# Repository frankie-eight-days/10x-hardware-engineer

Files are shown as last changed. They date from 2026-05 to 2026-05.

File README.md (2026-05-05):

# 10x Hardware Engineer

An experiment in agent-driven, full-stack open-source hardware: design a Linux-class dev board from datasheet to shell prompt with as much LLM automation as physically possible, then write up what worked and what didn't.

## The board

**Target MPU:** NXP i.MX 6ULL (MCIMX6Y2CVM08AB, ~$5–6 @ qty 10)
- Cortex-A7 @ 800 MHz, MAPBGA-289, 0.8 mm pitch (forgiving for an open-stack BGA fanout)
- External DDR3, 2× 10/100 Ethernet MAC, USB 2.0 OTG, I²S, UART, SPI, USDHC
- Mainline Linux + U-Boot, NXP Yocto BSP, Olimex OLinuXino open KiCad reference

**Peripherals (v1 spec):**
- 256–512 MB DDR3L (Micron / Nanya, 16-bit, JLC stock permitting)
- 1× RJ45 Ethernet (LAN8720A or KSZ8081 PHY) — talk to it over the home LAN
- USB 2.0 host/OTG (also doubles as i.MX serial-download recovery — unbrick without JTAG)
- microSD slot (primary boot)
- Optional QSPI / eMMC footprint (stretch)
- I²S Class-D audio amp (MAX98357A) + speaker pads — fun ngspice subject
- USB-UART bridge (CH340N, JLC Basic) for the shell, plus 4-pin TTL UART header
- 10-pin Cortex JTAG/SWD header (don't ship without it)
- PMIC: PCA9450 or PF3000 (TBD — pick what JLC has stocked)

## The stack

| Layer | Tool | Notes |
|---|---|---|
| Datasheet RAG | Docling → LanceDB hybrid → custom FastMCP | Required citations on every answer |
| Block diagrams | Mermaid (source-of-truth) + drawio MCP | mermaid diffs in git, drawio for blog |
| Schematic | atopile (`.ato`) | parametric `pick_part`, JLC-aware |
| Parts | jlcparts SQLite + easyeda2kicad | offline part DB + symbol/footprint pulls |
| Layout | KiCad 9 + Seeed kicad-mcp-server | 39-tool MCP |
| Routing | KiCad PNS (DDR3, USB, ENET) + Freerouting CLI (boring nets) | hybrid; agent does length-tune constraints |
| Sim | ngspice + InSpice | power rails, PMIC loop, Class-D filter |
| Fab/PCBA | JLCPCB API | basic/preferred parts where possible |
| Firmware build | Buildroot + mainline U-Boot + mainline Linux | Yocto is overkill |
| Firmware debug | OpenOCD + JTAG + serial-download recovery | |
| LLM | Opus 4.7 (1M) for layout/DDR; Sonnet 4.6 for cheap Q&A | prompt-cache datasheet + HDG |

## Phases

1. **Hardware capture** — block diagram → atopile modules → KiCad netlist → BOM
2. **Layout** — placement, BGA escape, DDR3 length-matching, Ethernet diff pairs, fab files
3. **Bring-up** — power-on, UART, U-Boot from SD
4. **Linux** — kernel + Buildroot rootfs, shell over UART
5. **Network** — DHCP, SSH from laptop
6. **Audio demo** — I²S out to the Class-D amp, play a sine wave from userland
7. **Blog** — honest write-up: what the agents did, what they got wrong, where humans had to step in

## Why this is supposed to be novel

Quilter shipped an i.MX 8M Mini DDR4 board with an autonomous physics engine in 40 hours — closed-source. atopile / tscircuit / Diode have shipped public LLM-driven schematics but only on 2-layer ESP32-class boards. **Nobody has publicly crossed the DDR Rubicon on a fully open agent stack.** That's the gap.

## Status

Scaffolding. See [PLAN.md](PLAN.md) for the decision log and open questions.

## License

MIT.

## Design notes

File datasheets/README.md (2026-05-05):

# Datasheets

PDFs are git-ignored (too big). Fetch with `scripts/fetch_datasheets.sh` (TODO) or by hand.

## Acquired

| File | Pages | Source | Notes |
|---|---|---|---|
| `raw/imx6ull-MCIMX6Y2CVM08AB-datasheet.pdf` | 138 | bundled with reference design | NXP i.MX 6ULLIEC rev 1.2 (2017). Full electricals + ordering + DDR/MMDC + boot config. Authoritative. |
| `raw/imx6ull-hardware-guide.pdf` | 12 | nxp.com (AN5121) | i.MX 6ULL Hardware Design Checklist — short. |
| `raw/ddr3-nanya-NT5CC128M16JR.pdf` | — | bundled | Nanya 2 Gb DDR3-1600 ×16. **Probable DDR3 choice.** |
| `raw/ref-bundle/NT5CC256M16{DP,EP}.pdf` | — | bundled | Nanya 4 Gb DDR3 alternates. |
| `raw/emmc-MKEMB008GT1E.pdf` | — | bundled | 8 GB eMMC (stretch goal). |
| `raw/imx6ull-core-board-reference-schematic.pdf` | — | bundled | Full schematic of `yu-mingfu/IMX6ULL_Core_Board` — DDR3 byte-lane wiring, power tree, eMMC, connector. **Crib heavily.** |
| `raw/imx6ull-reference-manual.pdf` | **3899** | whqee.cn mirror | NXP **IMX6ULLRM Rev 0** (Sep 2016). Full register-level manual. Authoritative. |
| `raw/imx6ull-hardware-developer-guide.pdf` | 53 | zlgmcu.com mirror | NXP **IMX6ULLHDG Rev 0** (Aug 2016). DDR3 + USB + Ethernet routing rules. |

## Still pending

- **AN5198** — i.MX 6UL/6ULL DDR Calibration.
- **AN12042** — i.MX 6UL/6ULL DDR3L Layout Guidelines.
- **AN5187** — Power Consumption.

## Pending fetch (public)

- Datasheets for our peripheral choices once finalized:
  - PMIC: PCA9450 / PF3000 / PF1550
  - Ethernet PHY: LAN8720A or LAN8742A
  - I²S amp: MAX98357A
  - USB-UART: CH340N
  - microSD socket: Hirose DM3 / Molex 502774

## Next step (RAG ingest)

Run **Docling** on every PDF in `raw/` → `parsed/` markdown + figure PNGs + per-page citations. Index with LanceDB hybrid (BM25 + dense embeddings). Serve via custom FastMCP at `mcp/datasheet-server/` exposing `lookup_register`, `lookup_pin`, `get_electrical_limit`, `get_routing_rule`. See repo `PLAN.md` for the full RAG strategy.

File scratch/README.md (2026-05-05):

# scratch

Throwaway atopile experiments — not the real board. Used to validate the toolchain and try syntax.

## hello_resistor

Single 10 kΩ pull-down on a 3.3 V rail. Verifies parse → solve → pick LCSC part → emit KiCad PCB + BOM + datasheet.

```bash
cd hello_resistor/my_first_ato_project
ato build
```

Picked part on first run: UNI-ROYAL `0402WGF1002TCE` (LCSC `C25744`), a 10 kΩ ±1% 0402 resistor.

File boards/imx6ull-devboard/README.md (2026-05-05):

# i.MX 6ULL Dev Board

See repo root [README.md](../../README.md) and [PLAN.md](../../PLAN.md).

## Layout

- `hardware/` — atopile sources, KiCad project, mermaid block diagrams, ngspice decks
- `firmware/` — Buildroot config, U-Boot patches, Linux device tree

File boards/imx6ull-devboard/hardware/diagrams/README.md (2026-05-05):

# Diagrams

Mermaid is the source-of-truth (text, diffs cleanly with `.ato`). Render via:

- **VS Code:** Markdown Preview Mermaid extension renders inline.
- **CLI:** `npx -p @mermaid-js/mermaid-cli mmdc -i system.mmd -o system.svg`
- **Quick view:** paste into https://mermaid.live
- **Drawio (presentation):** drawio MCP `open_drawio_mermaid` tool

## Files

- `system.mmd` — top-level block diagram. MPU + DDR3 + Ethernet + USB + audio + debug + power input.
- `power_tree.mmd` — focused view of the discrete buck/LDO chain with currents and sequencing notes.

## Notes

- **Two USB-C connectors** — one power-only (CC1/CC2 → HUSB238), one data-only (D+/D- → MPU USB OTG). Simpler routing than combining; trivially distinguishable by silkscreen. Both use the same TYPE-C-31-M-17 part for BoM consolidation.
- **Boot mode select**: 2-position DIP shown for SD vs USB serial-download recovery. i.MX 6ULL boot ROM supports many sources via BOOT_CFG fuses+pins; the DIP is a subset.
- **UART console**: CH340N + USB-A AND a 4-pin TTL header on the same MPU UART1 lines. Belt-and-suspenders for first bring-up.

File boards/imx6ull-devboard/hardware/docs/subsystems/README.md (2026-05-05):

# Subsystem design docs

One file per subsystem in the system block diagram. Each documents:

- **Role** in the board
- **Parts chosen** with LCSC + datasheet citations
- **First-principles reasoning** behind values that aren't directly from datasheets
- **Open questions / TODOs**

Living docs — update as the design evolves. Treat this as the engineering notebook that will feed the blog post.

## Files

- `ethernet.md` — RMII PHY + RJ45 + magnetics
- `power_input.md` — USB-C PD sink + bench supply OR + reverse polarity
- `power_tree.md` — discrete buck/LDO chain from 5V_BOARD
- `usb_uart.md` — CH340N USB-UART bridge for console
- `audio.md` — MAX98357A I²S Class-D amplifier
- `microsd.md` — boot SD slot
- `debug.md` — JTAG header, reset, boot DIP, status LEDs, coin cell
- `mpu.md` — i.MX 6ULL pin mapping + decoupling + reference connections
- `ddr3.md` — SDRAM single-chip, byte-lane wiring, layout requirements

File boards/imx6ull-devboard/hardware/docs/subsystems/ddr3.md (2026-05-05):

# DDR3 SDRAM subsystem

## Role

Main system memory for the i.MX 6ULL. Single-chip 16-bit DDR3L providing 256 MB at the MPU's MMDC interface. Required for U-Boot / Linux to load (i.MX boot ROM has only 128 KB ROM + 256 KB OCRAM).

## Architecture

```
i.MX 6ULL MMDC (MPU.ddr3 bus, 1.35V signaling)
  │
  ├── DRAM_ADDR[0..13] ──────── A0..A13          (14 row/col lines)
  ├── DRAM_SDBA[0..2] ────────── BA0, BA1, BA2    (3 bank select)
  ├── DRAM_DATA[0..7] ────────── DQL0..DQL7       (lower byte lane)
  ├── DRAM_DATA[8..15] ───────── DQU0..DQU7       (upper byte lane)
  ├── DRAM_DQM[0] ────────────── DML              (lower byte mask)
  ├── DRAM_DQM[1] ────────────── DMU              (upper byte mask)
  ├── DRAM_SDQS0_P/N ─────────── DQSL / DQSL#     (lower byte strobe pair)
  ├── DRAM_SDQS1_P/N ─────────── DQSU / DQSU#     (upper byte strobe pair)
  ├── DRAM_SDCLK0_P/N ────────── CK / CK#         (system clock pair)
  ├── DRAM_SDCKE0 ────────────── CKE              (clock enable)
  ├── DRAM_CS0_B ─────────────── CS#              (chip select)
  ├── DRAM_RAS_B / CAS_B ─────── RAS# / CAS#
  ├── DRAM_SDWE_B ────────────── WE#
  ├── DRAM_ODT0 ──────────────── ODT              (on-die termination ctrl)
  ├── DRAM_RESET ─────────────── RESET#
  └── DRAM_VREF (0.675V) ─────── VREFCA + VREFDQ  (shared, single divider)

External per Nanya datasheet:
  ZQ pad → 240Ω 1% → GND  (impedance calibration)
  VDD/VDDQ × ~12 pins → 12× 100nF X7R 0402 + 2× 10µF X5R 0805 bulk
```

## Part choice

| Role | MPN | LCSC | Stock |
|---|---|---|---|
| DDR3L SDRAM | Nanya NT5CC128M16JR-EK | C428583 | 79 ⚠️ low |

**Backup:** Micron MT41K128M16JT-125 (pin-compatible, more stock).

## Datasheet anchors (Nanya version 1.5 04/2019)

- **Page 1**: features, programmable functions, package summary
- **Page 5**: 96-ball TFBGA top-view ball map (used for atomic-part pinout)
- **Pages 6-7**: ball descriptions + power supply requirements
- **Pages 9-12**: power-on initialization sequence (200µs stable → RESET# released → 500µs → MR2/MR3/MR1/MR0 → ZQCL)

## First-principles design notes

### Why x16 single-chip instead of two x8

i.MX 6ULL MMDC supports 16-bit or 32-bit DDR3 buses. We use 16-bit. Two options:
- **One x16 chip** (this design): 2× fewer chips, fewer balls to fan out, simpler T-topology, 256 MB capacity.
- **Two x8 chips**: more capacity (512 MB) but doubles BGA fanout work, requires fly-by routing for clocks/address with proper termination, ×2 power, ×2 decoupling.

For a dev board where 256 MB is plenty for Linux + apps, **one x16 chip** is the right tradeoff. Industry convention for sub-$10 single-chip boards.

### Why DDR3L (1.35V) not DDR3 (1.5V)

- i.MX 6ULL natively supports both. NVCC_DRAM is the rail and we picked 1.35V from the buck because:
  - **Power**: 1.35V × draw is ~25% less than 1.5V × draw → less heat
  - **Datasheet compatibility**: NT5CC...JR-EK is dual-voltage capable (per page 1 footnote)
- Tradeoff: DDR3L is ~10% slower spec for the same speed grade because of lower drive amplitude. Not a problem at our DDR3-1600 target.

### Single VREF for both VREFCA and VREFDQ

JEDEC JESD79-3 allows VREFCA and VREFDQ to share one supply for "low noise" applications (i.e., single-chip). For multi-DRAM-rank designs you'd want separate dividers per chip for isolation, but with one chip we tie VREFCA + VREFDQ together to the existing 1k/1k divider already in the MPU module.

The MPU module's `package.DRAM_VREF` is the i.MX 6ULL's single Vref output which we drive into both VREFCA and VREFDQ on the DDR3 chip.

**TODO:** add `vref` field to `DDR3Bus` interface in mpu.ato + wire from MPU to DDR3 chip.

### ZQ calibration: 240Ω 1% to GND

Required by JEDEC for output driver impedance calibration. Single 240Ω 1% 0402 resistor from the chip's ZQ ball (L8) directly to GND. Place near the chip; don't share with anything else.

### Decoupling: ~12× 100nF per VDD/VDDQ ball + bulk

Looking at the 96-ball top-view ball map, count of supply pins:
- **VDD**: B2, D9, G8, K2, K8, N1, N9, R1, R9 = 9 pins
- **VDDQ**: A1, A8, C1, C9, D2, E9, F1, H2, H9, plus VSSQ-pairs = ~9 pins
- **VSS / VSSQ**: many

Datasheet implicit recommendation (typical for DDR3L x16): one 100nF X7R 0402 per ball, plus 2-3× 10µF X5R 0805 bulk close to the chip on the 1V35 rail. We commonize 100nF (already 20+ in BOM).

### RESET# handling

Active low. **Held below 0.2×VDD during power-on for 200µs minimum.** `DRAM_RESET` from the MPU drives this directly; the MPU's MMDC controller manages the init sequence in firmware. 100kΩ pull-down on RESET# is good practice (already in i.MX 6ULL by way of internal pulldown — confirm in HDG; if not, add external).

### Layout-time TODOs (not in atopile, in KiCad)

This module produces **netlist only**. The hard work happens in KiCad:

1. **Length-matching groups** per i.MX 6ULL HDG / AN12042 DDR3L Layout Guidelines:
   - **Address/control + clock** group: match within ±25 mil; CK pair to be the slowest
   - **Byte 0 group**: DQ0-7, DM0, DQS0/DQS0# match within ±25 mil; reference DQS0
   - **Byte 1 group**: DQ8-15, DM1, DQS1/DQS1# match within ±25 mil; reference DQS1
   - **Diff pairs**: CK/CK# and both DQS pairs intra-pair match ±5 mil
2. **Continuous reference plane** under DDR3 traces (no plane splits)
3. **Short, point-to-point** routing (T-topology not needed for single chip)
4. **Place chip ≤30 mm from MPU** to keep within timing budget
5. **Impedance**: 50Ω single-ended, 100Ω diff; rely on stackup target

## Module API

```ato
module DDR3:
    power_1v35 : ElectricPower    # NVCC_DRAM
    bus        : DDR3Bus          # imported from mpu.ato
    vref       : Electrical       # shared VREFCA + VREFDQ from MPU's divider
```

## Open questions / TODOs

- [x] Add `vref` to DDR3Bus interface in mpu.ato; wire `package.DRAM_VREF` to it. **DONE.**
- [x] Confirm Nanya NT5CC128M16JR EasyEDA symbol pin numbering. **Partially:** found the DQSL/DQSL# pair was swapped, fixed. Found 6 NC pads (J1, J9, L1, L9, M7, T7) missing from the auto-gen, added.
- [x] Prefix DDR3 address signals (`DDR_A0`, `DDR_A4`, etc.) to avoid name collisions with MPU BGA pad coordinates A4/A5/A6/A11/A13. **DONE.**
- [x] Resolve `min() iterable argument is empty` build crash. **DONE** — see "Build blocker" section above; root cause was atopile bbox bug on circle-only silkscreen, fixed by adding `fp_rect` body outline.
- [ ] Decide if we need a 100kΩ pulldown on DRAM_RESET externally.
- [ ] First-article: scope CK/CK# at the chip with a high-Z probe — confirm differential swing, no overshoot.
- [ ] Reviewer agent run after schematic is in place.
- [ ] File the `get_bbox_from_geos` Circle/Arc bug upstream at github.com/atopile/atopile.

## Build blocker — RESOLVED (upstream atopile bug)

The earlier `min() iterable argument is empty` crash during the PCB-write stage
turned out to be an **atopile bug**, not a schematic issue. Resolved 2026-05-05.

**Root cause:** `faebryk/exporters/pcb/kicad/transformer.py:get_bbox_from_geos`
has unimplemented `...` stubs for the `Circle` and `Arc` branches:

```python
elif isinstance(geo, kicad.pcb.Circle):
    # TODO: calculate extremes.extend([geo.center, geo.end])
    ...
```

When `set_designator_positions` runs on a *new* footprint (added in this build),
it computes the silkscreen bounding box. The Nanya footprint that `ato create
part` imported from EasyEDA has 96 `fp_circle` shapes on `F.SilkS` (one per
ball, decorative) and **zero** `fp_line`/`fp_rect`/`fp_arc`. So `extremes`
stays empty, and the chained `Geometry.bbox` call eventually does `min(...)`
on `[]`.

**Fix applied:** added a single `fp_rect` body outline to the Nanya .kicad_mod:

```kicad_mod
(fp_rect
    (start -3.75 -6.5)
    (end 3.75 6.5)
    (stroke (width 0.12) (type solid))
    (fill no)
    (layer "F.SilkS")
    (uuid "00000000-0000-0000-0000-000000000001")
)
```

Corners match the 7.5 × 13.0 mm package body from the filename
`TFBGA-96_L13.0-W7.5...`. This also gives the BGA a proper silkscreen body
outline on the assembled board — strictly an improvement over the 96 floating
circles.

**How the actual stack trace was found** (worth noting for future opaque
atopile errors): the `min()` message printed by `ato build` is just the
exception message; the full traceback is logged to
`~/Library/Logs/atopile/build_logs.db` table `logs`, column `python_traceback`
as JSON. Query with:

```bash
sqlite3 ~/Library/Logs/atopile/build_logs.db \
  "SELECT python_traceback FROM logs \
   WHERE message='min() iterable argument is empty' \
   ORDER BY id DESC LIMIT 1"
```

The earlier "Renaming net `D7`→…" diagnostic clue was a red herring — those
are normal info logs emitted as nets get processed; the crash happens later
in `update_pcb` → `set_designator_positions` → `get_bounding_box`, which has
nothing to do with net renaming.

**Should also be filed upstream:** atopile/faebryk should implement the Circle
and Arc bbox branches (the math is straightforward: for Circle, extents are
`(center.x ± radius, center.y ± radius)`).

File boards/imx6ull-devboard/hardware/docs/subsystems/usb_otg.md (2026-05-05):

# USB-C #2 — USB OTG1 connector

## Role

Second USB-C receptacle on the board, wired to the i.MX 6ULL's **USB OTG1**
peripheral. Acts as a USB **device** (UFP) by default — host PC enumerates
the board as a gadget (CDC-ACM serial, USB-Ethernet, mass storage, fastboot,
whatever the kernel exposes). USB-C #1 is power-only (HUSB238 PD), USB-C #3
is the CH340 console.

## Architecture

```
USB-C connector (USB2_0TypeCHorizontalConnector from atopile/usb-connectors)
  │
  ├── 5.1kΩ pulldowns on CC1 + CC2  → declares device-mode (UFP)
  ├── 1A polyfuse on VBUS           → fault protection
  ├── USBLC6-2SC6 ESD on D+/D-      → ±15kV cable-side protection
  │
  ├── VBUS (5V from cable) ─── 100Ω ─── i.MX USB_OTG1_VBUS  (detect ≥4.4V)
  ├── D+/D-                ────────── i.MX USB_OTG1_DP / DN
  └── GND ────────────────────────── system GND

i.MX OTG1 ID pin (GPIO1_IO00 ALT2 = ANATOP_OTG1_ID)
  └── 100kΩ pull-up to 3V3 (inside MPU module) → device-mode default
```

## Why UFP-only in v0

Full USB-C OTG with role detection requires a CC-monitoring chip
(TUSB320LAI, FUSB302, etc.). These add cost + pinmux + a Linux driver and
aren't needed for a dev board where the typical use case is:

> Plug board into laptop → board appears as `/dev/ttyACM0` and `usb0`
> network interface.

CC pulldowns alone are enough to advertise UFP behavior to a USB-C host,
which then injects 5V VBUS. The MPU sees VBUS ≥4.4V on USB_OTG1_VBUS and
the controller starts in device mode.

For host-mode operation in v2: replace this subsystem with one that
includes a TUSB320LAI driving USB_OTG1_ID.

## Why the 100Ω in series with VBUS detect

NXP AN12028 §"USB VBUS Detection" recommends a 100Ω current-limit resistor
in series with `USB_OTG1_VBUS`. The on-chip VBUS_VALID comparator threshold
is ~4.4V (range 4.0–4.8V) and the pin is rated 5.5V abs. The 100Ω limits
in-rush + ESD bleed-through without dropping VBUS below the threshold.

> **Earlier bug:** the original wiring used a 20kΩ/30kΩ divider that pulled
> VBUS down to 3V at the chip pin. With the threshold at 4.4V the chip
> would never see "VBUS present" and OTG1 would never enable. **Fixed.**

## Why ID is pulled HIGH

i.MX 6ULL ANATOP_OTG1_ID convention:
- ID **HIGH** (or floating, internal pull-up enabled) → device mode
- ID **LOW** (grounded) → host mode

100kΩ pull-up to 3V3 on GPIO1_IO00 inside the MPU module forces device
mode. Cheap, deterministic, won't fight any host that mistakenly drives ID.

## Module API

```ato
module USBOtg:
    power_5v_vbus = new ElectricPower    # 5V VBUS from host cable (after fuse)
    usb_dp_dn     = new DifferentialPair # to mpu.usb_otg1
```

VBUS is exposed because the MPU module needs it for VBUS_VALID detect.

## Open / TODOs

- [ ] **v2:** add TUSB320LAI for full USB-C OTG role detection.
- [ ] First-article: confirm host enumeration on a Linux laptop +
      confirm VBUS_VALID asserts within 100ms of cable insert (USB CDC spec).
- [ ] Layout: keep D+/D- diff-pair length matched to ±50 mil, 90Ω
      differential impedance.

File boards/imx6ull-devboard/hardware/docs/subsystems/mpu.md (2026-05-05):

# MPU subsystem (i.MX 6ULL)

## Role

The brain. Wraps the MCIMX6Y2CVM08AB BGA-289 package with all the rails, decoupling, crystals, and exposed buses for the rest of the board.

## Architecture

```
                  ┌─────────────────────────────────────────┐
                  │         i.MX 6ULL (MCIMX6Y2CVM08AB)     │
   power_3v3 ────▶│ VDD_HIGH_IN, NVCC_*, VDDA_ADC_3P3       │
   power_1v4_arm ▶│ VDDARM_IN                               │
   power_1v4_soc ▶│ VDDSOC_IN                               │
   power_1v35 ───▶│ NVCC_DRAM ×6                            │
   power_snvs ───▶│ VDD_SNVS_IN                             │
                  │                                          │
                  │ Internal caps: VDD_*_CAP × 6 (1 µF each)│
                  │                                          │
   24 MHz xtal ──▶│ XTALI/XTALO (CCM main clock)            │
   32.768k xtal ▶│ RTC_XTALI/RTC_XTALO (RTC for SNVS)      │
                  │                                          │
                  │ Exposed buses:                           │
                  │   ddr3_bus (50+ signals to DDR3 chip)   │
                  │   rmii, mdio, enet_reset → Network       │
                  │   usdhc1 → MicroSD                       │
                  │   usb_otg1 → USB-C #2                    │
                  │   uart2 → USBUart console                │
                  │   sai2 → Audio                           │
                  │   jtag, reset → Debug                    │
                  │   boot_mode0/1, heartbeat, sd_cd → Debug │
                  └─────────────────────────────────────────┘
```

## Pin/ball groups (from datasheet §3 Modules List)

### Power supplies (must all be connected)

| Rail | i.MX pin name | Source | Decoupling |
|---|---|---|---|
| 3V3 | VDD_HIGH_IN | power_3v3 | 1× 4.7µF + 1× 100nF |
| 3V3 | NVCC_GPIO, NVCC_NAND, NVCC_LCD, NVCC_CSI, NVCC_ENET, NVCC_SD1, NVCC_UART, NVCC_PLL | power_3v3 | 1× 100nF each |
| 3V3 | VDDA_ADC_3P3, ADC_VREFH | power_3v3 (with ferrite filter ideally) | 1× 100nF + 1× 1µF |
| 1.4V | VDDARM_IN | power_1v4_arm | 1× 100nF + 1× 10µF |
| 1.4V | VDDSOC_IN | power_1v4_soc | 1× 100nF + 1× 10µF |
| 1.35V | NVCC_DRAM ×6 (M6, L6, K6, J6, H6, G6) | power_1v35 | 6× 100nF + 1× 22µF bulk |
| 3V SNVS | VDD_SNVS_IN | power_snvs | 1× 100nF + 1× 1µF |
| Internal | VDD_ARM_CAP ×4, VDD_SOC_CAP, VDD_HIGH_CAP, VDD_SNVS_CAP, VDD_USB_CAP, NVCC_DRAM_2P5 | (output cap from internal LDO) | 1µF X7R 0402 each |

Total decoupling: ~25 caps. Heavy commonization: most are 100nF X7R 0402 (already common); the bulk 22µF for DDR is one new line item.

### Crystals

- **24 MHz (CCM main)**: `XTALI` / `XTALO`. 18–22 pF load caps. Per i.MX 6ULL HDG §"Clocking", load capacitance per leg ≈ `2·(CL - C_stray) ≈ 22 pF` for CL=12 pF crystals.
- **32.768 kHz (RTC)**: `RTC_XTALI` / `RTC_XTALO`. 12.5 pF crystal, with internal load caps in the SNVS domain — only the crystal is needed externally per HDG §"RTC".

### DDR3 bus (50+ signals, all dedicated balls)

Exposed as a `DDR3Bus` interface that the DDR3 module connects to:

- DRAM_ADDR[15:0] — 16 address lines
- DRAM_DATA[15:0] — 16-bit data
- DRAM_DQM[1:0], DRAM_SDQS[1:0]_P/N — byte-lane mask + diff strobes
- DRAM_SDCKE[1:0], DRAM_SDCLK0_P/N, DRAM_SDBA[2:0] — control + bank
- DRAM_RAS_B, DRAM_CAS_B, DRAM_SDWE_B — row/col/write enable
- DRAM_CS[1:0]_B, DRAM_ODT[1:0] — chip select + on-die termination
- DRAM_RESET — DDR3 reset
- DRAM_VREF — 0.5 × NVCC_DRAM reference (single-ended VTT/VDDQ ref)
- DRAM_ZQPAD — ZQ calibration (240 Ω resistor to ground)

For our single-chip 16-bit DDR3, only CS0/ODT0 and SDCKE0 are used. CS1/ODT1/SDCKE1 left floating.

### Direct-to-peripheral balls (no IOMUXC mux required)

| Peripheral | Balls |
|---|---|
| ENET1 RMII | ENET1_TX_CLK, ENET1_TX_EN, ENET1_TX_DATA0/1, ENET1_RX_EN, ENET1_RX_ER, ENET1_RX_DATA0/1 |
| USDHC1 | SD1_CLK, SD1_CMD, SD1_DATA0–3 |
| USB OTG1 | USB_OTG1_DP, USB_OTG1_DN, USB_OTG1_VBUS, USB_OTG1_CHD_B |
| UART2 (console) | UART2_TX_DATA, UART2_RX_DATA |
| JTAG | JTAG_TCK, JTAG_TMS, JTAG_TDI, JTAG_TDO, JTAG_TRST_B, JTAG_MOD |
| Boot mode | BOOT_MODE0, BOOT_MODE1 |
| Reset | POR_B |
| Power button | ONOFF (tied high via 100kΩ to VDD_SNVS to keep board on) |

### IOMUXC-muxed peripherals (TODO from pinmux research)

These need ball-to-alt-function decisions. Pending research agent results:

- **SAI2 I²S** (TX_BCLK, TX_SYNC, TX_DATA) → likely on CSI_DATA / LCD_DATA / NAND_DATA balls
- **MDIO/MDC** for ENET1 → likely on GPIO1_IO06/07
- **I²C1** (SCL, SDA) for any future expansion → likely on UART4_TX/RX

Once the research agent returns the canonical pinmux, fill in here.

## First-principles design notes

### Decoupling philosophy

i.MX 6ULL has dozens of power balls. Per the HDG §"Power Supply Decoupling": one **100 nF X7R 0402 per ball**, placed within 5 mm of the package. Plus **bulk capacitance per rail** (≥10 µF) within 30 mm. We commonize at the 100 nF and 10/22 µF level — that's ~25 individual 100 nF caps but only one BOM line.

Internal LDO caps (`VDD_*_CAP`): per datasheet §3.1.3, each gets a **1 µF X7R 0402** between the cap pin and GND. These are decoupling for the on-die regulators that produce VDD_HIGH (2.5V), VDD_SOC, VDD_ARM, etc. Not optional.

### DRAM_VREF: 0.5 × VDDQ via 1% divider

Datasheet §"DDR3L Interface" requires DRAM_VREF = NVCC_DRAM / 2 ± 1 %. Two **1 kΩ ±0.1 % resistors** in series from NVCC_DRAM to GND, midpoint to DRAM_VREF, with a **100 nF + 10 nF** filter cap. 1 % matched resistors hold tolerance.

### DRAM_ZQPAD: 240 Ω 1 % to GND

DDR3 ZQ calibration reference. **Single 240 Ω 1 % 0402** from DRAM_ZQPAD to GND. Sets the impedance for output drivers via the chip's internal calibration.

### ONOFF strap

Per datasheet, ONOFF must be tied to VDD_SNVS via 100 kΩ pull-up to keep the board in "on" state continuously. If we ever want a power-button feature, a SPST momentary to GND on this pin would toggle it. v0: just pull high.

### Boot mode wiring

BOOT_MODE0/1 from Debug subsystem (via 2-pos DIP). i.MX 6ULL boot ROM samples these at reset; default position selects "internal boot from BT_CFG straps." BT_CFG straps default to "probe USDHC1 → USDHC2 → NAND → eMMC" for SD-first boot — no extra straps needed for our case.

### POR_B handling

POR_B is the master reset. Routed to:
- Reset button (Debug)
- JTAG header pin 10 (nSRST)
- 10 kΩ pull-up to 3V3 (Debug-side)
- 100 nF debounce cap to GND (Debug-side)

### Unused peripheral straps

**TEST_MODE**: must be tied to GND (datasheet §"Special Signal Considerations"). Critical — board won't function if TEST_MODE floats high.

**Reserved/unused**: NGND_KEL0, GPANAIO, JTAG_MOD (typically pulled low), unused USB_OTG2, unused UART3-5, unused CSI_*, unused LCD_DATA*. Tie unused inputs to GND or 3V3 per HDG §"Recommended Connections for Unused Analog Interfaces."

For v0 we connect only the peripherals we use; unused balls are left floating in atopile (atopile WILL warn but won't fail). Layout-time we'll add tie-downs for the critical unused-input pads.

## Module API

```ato
module MPU:
    # Power rails
    power_3v3      : ElectricPower
    power_1v4_arm  : ElectricPower
    power_1v4_soc  : ElectricPower
    power_1v35     : ElectricPower
    power_snvs     : ElectricPower

    # DDR3 — exposed as bus
    ddr3           : DDR3Bus

    # Peripherals
    rmii           : RMII
    mdio           : MDIO
    enet_reset     : ElectricLogic       # MPU drives, active-low
    usdhc1_cmd     : ElectricLogic
    usdhc1_clk     : ElectricLogic
    usdhc1_dat     : ElectricLogic[4]
    sd_cd          : ElectricLogic
    usb_otg1       : USB2_0
    uart2          : UART_Base
    sai2           : I2S
    jtag           : JTAG
    reset          : ElectricLogic
    heartbeat      : ElectricLogic
    boot_mode0     : ElectricLogic
    boot_mode1     : ElectricLogic
```

## Open questions / TODOs

- [ ] Pinmux research agent — fill in IOMUXC alt-function choices for SAI2, MDIO, I²C.
- [ ] Add 1µF X7R 0402 decap on every VDD_*_CAP pin (24 internal LDO caps).
- [ ] DRAM_VREF divider + DRAM_ZQPAD resistor.
- [ ] TEST_MODE strap (must = GND).
- [ ] ONOFF 100kΩ to VDD_SNVS.
- [ ] 24 MHz crystal + load caps (22 pF).
- [ ] 32.768 kHz crystal (RTC).
- [ ] Decide if we want the 3V3_ANALOG ferrite split for VDDA_ADC_3P3 (Ethernet review flagged this for cleaner SI on PHY VDDA — same question here for ADC).

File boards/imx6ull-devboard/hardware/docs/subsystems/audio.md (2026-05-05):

# Audio subsystem

## Role

I²S Class-D audio output so the board can play sound. Used for:

- The "is it alive" demo: `aplay /usr/share/sounds/alsa/Front_Center.wav` after Linux boots
- ngspice simulation subject for the LC output filter (good blog material)
- Stretch: stream audio over Ethernet, demonstrate end-to-end pipeline

## Architecture

```
MPU SAI (I²S)        MAX98357A (TQFN-16, 3×3mm)         Class-D BTL output
                      ┌─────────────────┐
   BCLK   ─────────── BCLK              │
   LRCLK  ─────────── LRCLK         OUTP┼──[ferrite + 1nF]── speaker_p
   SDO    ─────────── DIN          OUTN┼──[ferrite + 1nF]── speaker_n
                      VDD (3V3)         │
                      GAIN ─[GND]       │  +9dB gain
                      nSD ─[100k→VDD]   │  active, stereo (L+R)/2 mix
                      └─────────────────┘
```

~1.6 W into 4 Ω, ~0.9 W into 8 Ω at VDD = 3.3 V (per datasheet Fig. 1). The 3.2 W / 1.8 W headline numbers in the datasheet are at VDD = 5 V. Plenty for a "hello world" demo speaker.

## Part choices

| Role | Part | LCSC | JLC |
|---|---|---|---|
| Class-D amp | Maxim MAX98357AETE+T (TQFN-16) | C910544 | Extended |
| Output ferrite ×2 | Sunlord GZ2012D601TF (commonized w/ power tree) | C1017 | Extended |
| Speaker connector | 2-pin 2.54 mm header (TBD in Debug subsystem) | — | Basic |

## First-principles design notes

### Why MAX98357A (not TPA3110 / TAS5825 / PAM8302)

- **MAX98357A** is the standard hobby/maker I²S Class-D amp because the datasheet is short (~30 pages), I²S is direct (no I²C config), and the gain/mode are set by single-resistor straps. $1.17 on JLC.
- TAS5825 needs I²C config — adds bring-up complexity. We want "boots, plays sound" with zero firmware fiddling.
- TPA3110 is analog-input only (no I²S). Would need a DAC. Costs more total.
- PAM8302 — analog-only, smaller. No I²S.

MAX98357A wins on simplicity for a "hello world audio" demo.

### Channel mode: stereo (L+R)/2 mix

MAX98357A `nSD_MODE` has a **100 kΩ internal pulldown**. Mode bands per datasheet (absolute voltage at the pin, not ratio):

| nSD_MODE voltage | Mode |
|---|---|
| < 0.16 V | Shutdown |
| 0.16 – 0.77 V | Stereo (L+R)/2 sum |
| 0.77 – 1.4 V | Right channel only |
| > 1.4 V | Left channel only |

To get **Stereo sum** with VDD = 3.3V, we need the pin between 0.16 V and 0.77 V. With the 100 kΩ internal pulldown, an external pull-up R sets:

```
V_SD = VDD × 100kΩ / (R_ext + 100kΩ)
```

For V_SD = 0.30 V (mid-band): R_ext = 1 MΩ. We use **1 MΩ pull-up to VDD**.

(Reviewer caught a bug here — the original 100 kΩ pull-up gave V_SD = 1.65 V which is "Left only", not "Stereo sum". The pin doesn't snap to "VDD = stereo sum" as some Adafruit-derived diagrams suggest; it actually selects "Left only" at full VDD because >1.4 V band wins.)

### Gain: +9 dB

`GAIN_SLOT` pin selects:

| GAIN_SLOT connection | Gain |
|---|---|
| 100 kΩ to GND | +9 dB |
| Float | +12 dB |
| 100 kΩ to VDD | +6 dB |
| GND direct | +15 dB |
| VDD direct | +3 dB |

**+9 dB** (100 kΩ to GND) is the default for "loud-but-not-clipping" desktop volume on a typical 4 Ω speaker. Driven by reasoning: 3.3V × 0.9 (Class-D efficiency) → ~3W into 4Ω at clip. With +9 dB and 1Vrms full-scale audio (typical line level), you reach clip near full ALSA volume — exactly the right operating point.

### Output: filterless mode

Datasheet §"Output Filtering" recommends **filterless mode** for short speaker cables (< 30 cm) — that's our case. OUTP/OUTN go straight to speaker pads.

Earlier draft used ferrite + 1 nF as a "Class-D filter," but the LC corner of 600 Ω@100 MHz / 1 nF lands at ~16 MHz — way above Class-D's 300 kHz switching fundamental. That's an EMI snubber, not a filter; mixing it with a real LC filter is explicitly warned against in the datasheet ("do not use the optional ferrite-bead filter in conjunction with the optional Class-D filter"). So: filterless mode, layout-time mitigations (short twisted-pair speaker wires, GND pour underneath).

If we ever need long speaker cables, drop in **10 µH + 470 pF** per output (proper LC, ~70 kHz corner). v2 if needed.

### VDD decoupling

Datasheet specifies **1 µF + 100 nF per VDD pin**. The MAX98357A has two VDD pins (7 and 8). Layout-wise these are usually shared — one 1 µF + one 100 nF close to the package, plus a 10 µF bulk on the rail.

Using 100 nF X7R 0402 and 1 µF X5R 0402 — both already in the board's common cap selection.

### Why 3.3V VDD (not 5V)

MAX98357A spec: 2.5–5.5V. At 5V VDD, max output power is higher (~5W). At 3.3V VDD, max is ~3.2W into 4Ω. We don't need >3W for a dev board demo, and using **3.3V** lets us share the rail with everything else — no separate audio rail, no extra ferrite bead.

If first-article reveals we want louder output, hopping to 5V VDD is a pour-and-paste change in layout.

### Speaker connector

Punted to Debug subsystem. Will use a **2-pin 2.54 mm header** to allow trivial speaker wire push-on, or just bare pads if soldering directly. No connector cost.

## Module API

```ato
module Audio:
    power_3v3  : ElectricPower      # in (Audio runs from 3V3)
    i2s        : I2S                # to MPU SAI
    speaker_p  : Electrical         # post-filter to speaker connector
    speaker_n  : Electrical
```

## Reviewer findings (batch review 2026-05-04)

| Sev | Issue | Status |
|---|---|---|
| Critical | nSD_MODE 100kΩ to VDD = "Left only" not stereo sum | **FIXED** — changed to 1MΩ |
| High | Ferrite + 1nF output is EMI snubber, not Class-D filter | **FIXED** — filterless mode |
| High | SD_MODE walks through modes during VDD ramp | **NOTED** — chip latches stable mode after VDD settles; if first-article shows the wrong mode at boot, drive nSD_MODE from MPU GPIO (TODO v2) |
| Medium | Doc claimed 3.2W into 4Ω at 3V3 — actually ~1.6W | **FIXED** in this doc |
| Medium | i.MX SAI must be master (MAX98357A is always slave) | Note: configure SAI as master in MPU pinmux + device-tree |
| Low | EP thermal pad — verify ≥4 vias in layout | Layout-time check |

## Open questions / TODOs

- [ ] Speaker connector (2-pin header) lands in Debug subsystem.
- [ ] First-article: scope the OUTP/OUTN waveform to confirm filterless EMI is acceptable.
- [ ] If first-article shows boot-time mode-walk problems on nSD_MODE, drive from MPU GPIO.
- [ ] If we ever want stereo, use TAS5825 (more pins, I²C — defer to v2).

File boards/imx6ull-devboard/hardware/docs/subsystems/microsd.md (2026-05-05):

# microSD subsystem

## Role

Primary boot medium. i.MX 6ULL boot ROM reads U-Boot from microSD when BOOT_MODE pins select SD. Linux rootfs lives on the same card after first boot.

## Architecture

```
i.MX 6ULL USDHC1 ── SD 4-bit interface ── SOFNG TF-015 push-push slot
                                          │
                                          ├── VDD = 3V3 (no UHS-I voltage switch for v0)
                                          ├── CMD pull-up: 10kΩ → 3V3
                                          ├── DAT[3:0] pull-ups: 47kΩ → 3V3
                                          └── CD switch → GPIO with 100kΩ pull-up
```

## Part choices

| Role | Part | LCSC | JLC |
|---|---|---|---|
| microSD push-push slot | SOFNG TF-015 | C113206 | Extended |
| Pull-up resistors | 10 kΩ + 47 kΩ + 100 kΩ (commonized values) | various | Basic |

## First-principles design notes

### Pull-up strategy

The SD spec (Physical Layer Spec §3.2 "Bus Pull-ups") specifies:
- **CMD**: 10–100 kΩ to VDD. CMD is open-collector during card-arbitration; the bus must default high.
- **DAT0**: pull-up needed (acts as busy signal in some modes); 10–100 kΩ.
- **DAT1, DAT2, DAT3**: pull-ups optional but recommended for clean startup; 10–100 kΩ.
- **CLK**: NO pull-up — host-driven push-pull only.

We use:
- **CMD: 10 kΩ** — strongest end of spec for fast command edges
- **DAT[3:0]: 47 kΩ** — light pull-up, lower steady current
- 5 pull-ups total = 5 resistors, but values commonize with rest of board (10k is everywhere; 47k is one new R value)

### CD (card detect) switch

Mechanical switch in the slot — shorts pin 9 to GND when a card is inserted. We pull pin 9 high through 100 kΩ to 3V3, route to MPU GPIO. Linux device-tree property `cd-gpios` maps this for hot-insert detection.

Some boards use the `DAT3` line as a CD signal (card-side internal pull-up makes DAT3 high without a card). We're not using that — explicit mechanical CD switch is more reliable.

### VDD supply: direct 3V3 (no load switch in v0)

Datasheet recommends a P-FET load switch on SD VDD so the host can power-cycle the card (for re-init or to enter sleep). For v0, **VDD tied directly to 3V3** — saves the FET, saves layout complexity, matches Olimex / NXP eval-board references.

If we ever need card-power-cycle for reliability, the load switch is a single SOT-23 P-FET drop-in. Mark as TODO for v2.

### No UHS-I (1.8V signaling)

UHS-I requires a USDHC voltage selector pin (`VSELECT`) and a buck or LDO that can swap NVCC_SD between 3.3V and 1.8V at runtime. Adds a regulator + level-shift logic. **Not worth it for v0**: U-Boot loads at 25 MHz / Linux boots fine at 50 MHz on 3.3V signaling, and SD cards' UHS-I gives at most 2× speed (104 MB/s vs 50 MB/s) which doesn't matter for boot.

NVCC_SD1 just stays on 3V3.

### Decoupling

100 nF + 10 µF on VDD — same caps already in our common parts list.

## Module API

```ato
module MicroSD:
    power_3v3 : ElectricPower      # in (VDD = 3V3)
    cmd        : ElectricLogic     # to MPU USDHC1_CMD
    clk        : ElectricLogic     # to MPU USDHC1_CLK
    dat        : ElectricLogic[4]  # to MPU USDHC1_DATA[3:0]
    cd         : ElectricLogic     # to MPU GPIO (card-detect)
```

## Reviewer findings (batch review 2026-05-04)

| Sev | Issue | Status |
|---|---|---|
| High | VDD bulk 10µF undersized for 200mA SD inrush | **FIXED** — bumped to 22µF X5R 0805 |
| High | TF-015 CD switch pin mapping unverified | **TODO** — verify against SOFNG mechanical drawing (the part may use different pins for the discrete CD contacts vs the SD pinout's pin 9) |
| Medium | DAT pull-ups duplicate i.MX internal pulls | NOTED — keep external for deterministic startup; ~30kΩ effective draws negligible current |
| Medium | No ESD on user-touched card contacts | TODO — small TVS array (e.g. SP3010-04 or PRTR5V0U2X) |
| Medium | No card-power-cycle FET — wedged-card boot risk | **DOCUMENTED** — accepted for v0, dev-board can be physically power-cycled. v2 candidate. |
| Low | 50 MHz CLK EMI near MDI / antennas | **LAYOUT FLAG** — keep CLK trace >5 mm from any RF / Ethernet MDI traces; route under continuous GND plane. |

## Open questions / TODOs

- [ ] Verify SOFNG TF-015 mechanical CD switch contact pin numbers.
- [ ] When MPU pinmux lands, route USDHC1 to balls with NVCC_SD1 = 3V3 by default.
- [ ] First-article: try multiple SD-card brands; cheap cards have widely varying inrush.

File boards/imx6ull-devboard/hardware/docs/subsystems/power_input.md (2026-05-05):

# Power Input subsystem

## Role

Get 5V into the board, from either of two sources:

1. **USB-C #1 (PD sink)** via Hynetek HUSB238 — negotiates 5V from any USB-C source (PD-aware or default-Vsafe5V).
2. **Bench supply** via 2-pin terminal block, with reverse-polarity protection.

Both sources feed `5V_BOARD` through 5A Schottky diodes (manual-select OR — never both connected simultaneously).

## Architecture

```
USB-C #1 (TYPE-C-31-M-17, commonized)
    │ VBUS
    ├── HUSB238 [VIN]
    │      [VSET=GND] → request 5V default
    │      [ISET=GND] → request max current
    │      [CC1, CC2] → chip handles negotiation
    │      [GATE]     → unused in v0 (no external FET)
    │ VBUS                      ┐
    └────[SS54 Schottky D1]─────┤
                                 │
Bench input (DIBO 2-pin block)   │
    │  +              ┐          │
    └─[Source][AO3401A P-FET]    │
       │   [Drain]                │
       │      └──[SS54 D2]────────┤
       │                          │
       Vin- ───┬── Gate ─[10kΩ]──┘
               │
               GND ────────────── Board GND
                                  │
                                  ▼
                              5V_BOARD
                                  │
                            [bulk 100 µF + 10 µF + 100 nF]
```

## Part choices

| Role | Part | LCSC | JLC |
|---|---|---|---|
| USB-C connector | TYPE-C-31-M-17 (commonized) | C2765186 | Extended |
| PD sink controller | Hynetek HUSB238_002DD | C7471904 | Extended |
| Schottky 5A OR (×2) | MDD SS54 (commonized) | C22452 | Basic |
| P-FET reverse-polarity | AO3401A | C15127 | Basic |
| Terminal block 2-pin | DIBO DB910-6.35-2P-GN-S | C395872 | Extended |

## First-principles design notes

### Why HUSB238 (R-strap PD) over plain CC pulldowns

A USB-C device with just `5.1 kΩ pulldowns on CC1/CC2` will receive Vsafe5V from any compliant source — no PD negotiation. So why HUSB238?

- **PD sources hold their advertised 5V tighter** than raw Vsafe5V. With a PD contract, the source guarantees current capability (1.5A or 3A); without, it might fold back at 100 mA.
- **Future flexibility** — if we want to request 9V or 12V (e.g., to run a higher-current motor demo), we change the VSET strap resistor. No PCB respin.
- **Diagnostics** — HUSB238 has I²C registers exposing the negotiated contract; useful for blog content showing the agent reading state.

### VSET = GND for 5V request

HUSB238 datasheet table: VSET grounded directly = "request 5V default contract." Other configurations request 9/12/15/20V. We tie directly to GND.

### ISET = GND for max current

ISET pin sets the requested current. Tied to GND = "highest available." For 5V/3A the source will provide what it can. We're drawing far less than 3A so this is permissive.

### GATE pin: floating in v0

HUSB238 GATE drives an external N-FET that switches VBUS through to a downstream load only after PD negotiation succeeds. In v0 we leave it floating and use VIN directly via the Schottky — relying on USB-C's mandatory Vsafe5V default. **TODO v2**: add the AO3400A external switch FET for clean enable/disable.

### Schottky OR (no current-hogging)

Two SS54 5A Schottkys in OR. Manual-select (only one source plugged in at a time), so current-hogging via positive tempco is not a concern. ~0.55V drop @ 5A → board sees minimum 4.45V from a 5V source. All bucks/LDOs handle this comfortably.

### P-FET reverse polarity protection (bench input only)

User plugs bench supply, polarity not enforced by connector type. Reverse polarity is plausible.

**AO3401A topology:**
```
Vin+ ─[Drain]─[P-FET]─[Source]─ Vout+
                │
                └─ Gate ─[10kΩ]─ Vin- (board GND when correct polarity)
```

- **Correct polarity** (Vin+ positive): Source charges to Vin+, Gate stays at GND via R, Vgs = -Vin+ ≈ -5V → P-FET fully ON, ~50 mΩ Rds(on) → ~50 mV drop @ 1A.
- **Reverse polarity** (Vin+ negative): Source pulled negative, Gate stays at +Vin+ (now positive), Vgs = +5V → P-FET OFF. Body diode (drain→source) reverse-biased → blocks.

The 10 kΩ gate-to-GND resistor limits inrush gate current during transients.

### USB-C #1 D+/D- handling

USB-C #1 is power-only. D+/D- pins on the connector connect to HUSB238's D+/D- (used for BC1.2 detection if a legacy USB-A→USB-C adapter is in use). No board logic touches them. CC1/CC2 routing is to HUSB238 only.

### Bulk capacitance on 5V_BOARD

After the OR diodes, we add **100 µF + 10 µF + 100 nF** bulk on 5V_BOARD. Calc:

- TPS563201 startup inrush per buck: ~0.4 A for 1 ms = 0.4 mC charge each.
- Three bucks soft-starting nearly simultaneously: ~1.2 mC needed.
- A 100 µF cap supplies 1.2 mC at ΔV = Q/C = 1.2 mC / 100 µF = 12 mV — negligible droop.
- 10 µF MLCC for HF transient response, 100 nF for sub-µF noise.

### What the input subsystem does NOT do

Per the reviewer's note from Power Tree (Issue 7), inrush control during the *first* energization (when board input caps are at 0V) is NOT addressed by this module. A dedicated **inrush limiter** (NTC thermistor or MIC2026 load switch with Toff slew) would help if the bench supply trips on inrush. **TODO**: instrument first-power-on, decide if needed.

## Module API

```ato
module PowerInput:
    power_5v_out : ElectricPower    # 5V_BOARD downstream
```

(No external interfaces beyond the output rail — USB-C connectors and bench connector are integral.)

## Open questions / TODOs

- [ ] `ato create part` for AO3401A or use stdlib PFET — verify package="SOT-23" picks AO3401A automatically.
- [ ] ESD protection on USB-C #1 line side (TVS array on D+/D- + CC1/CC2).
- [ ] v2: add external switch FET on HUSB238 GATE for clean enable/disable.
- [ ] First-article: scope the bench-supply inrush. If >2 A, add NTC thermistor or load switch.

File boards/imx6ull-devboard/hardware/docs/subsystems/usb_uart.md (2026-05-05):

# USB-UART subsystem

## Role

USB-to-UART bridge so the host PC sees a `/dev/ttyUSB0` (Linux) / `/dev/cu.usbserial-*` (macOS) / `COMx` (Windows) when the dev board's console USB-C is plugged in. Used for:

- U-Boot console during first power-on
- Linux serial console (UART1 → CH340N → host)
- Bare-metal debug before USB stack is up

Belt-and-suspenders: the same MPU UART1 lines also go to a 4-pin TTL header for users who prefer their own FT232/CP2102 dongle, or for boot-time scope/logic-analyzer probing.

## Architecture

```
       USB-C #3 (TYPE-C-31-M-17, same part as #1 and #2, commonization)
            │ D+/D-/VBUS/GND/CC1/CC2
            ▼
  ┌─────────────────────┐
  │ CH340N (SOP-8)      │
  │ powered from 5V     │
  │ V3 internal LDO     │
  │ (100 nF decap)      │
  │                     │
  │ TXD ── MPU UART1_RX │   (3.3 V CMOS levels)
  │ RXD ── MPU UART1_TX │
  └─────────────────────┘
            │
            └── 4-pin header (3V3, GND, TX, RX) for USB-TTL fallback
```

CC1/CC2 of USB-C #3 carry 5.1 kΩ pulldowns (handled by the `usb-connectors` package — board acts as USB device).

## Part choices

| Role | Part | LCSC | JLC |
|---|---|---|---|
| USB-UART bridge | WCH CH340N | C2977777 | Extended ($3) |
| USB-C receptacle | TYPE-C-31-M-17 | C2765186 | Extended (already in BoM 3×) |
| Header | 4-pin 2.54 mm | generic | Basic |

## First-principles design notes

### Why CH340N (not FT232 / CP2102)

- **CH340N (SOP-8)**: $0.48, ~14k stock, includes integrated USB termination resistors, no crystal needed (built-in oscillator). 8-pin package = minimum BOM and minimum routing.
- FT232RL: more capable (modem control, CBUS) but ~$3, significantly higher cost. We only need TX/RX.
- CP2102N: similar capabilities to CH340N, comparable price, but worse JLC stock.

CH340N also has Linux/macOS/Windows host drivers in-tree (since kernel 4.18, since macOS 10.15, since Windows 10), no driver install needed today.

### Why power CH340N from 5V_BOARD (not VBUS)

Two options:

| Source | Pro | Con |
|---|---|---|
| VBUS (USB host) | Zero quiescent draw on board 5V when console unplugged | Backfeed risk on TX/RX when CH340N is off — TX into unpowered chip clamps via ESD diode, source current undefined |
| 5V_BOARD | Simple, deterministic, no backfeed | ~5–10 mA quiescent always |

5V_BOARD wins on simplicity. 5–10 mA on a dev board pulled by a bench supply is invisible. **Decision: 5V_BOARD.**

VBUS is left floating (only used by the connector itself).

### V3 pin decoupling

CH340N has an internal 3.3V LDO (V3 pin output). Datasheet requires a **100 nF X7R decap** from V3 to GND. V3 is not exposed externally — it powers the internal logic and IO. We just place the cap.

### TX/RX routing

- CH340N **TXD** is its UART output — connects to MPU **UART1_RX** (i.MX 6ULL receives from CH340N's transmit).
- CH340N **RXD** is its UART input — connects to MPU **UART1_TX**.
- This mirror is the easy thing to get wrong; cite name explicitly.
- 3.3V CMOS levels both sides (CH340N IO sourced from internal 3V3, i.MX 6ULL NVCC_NAND on UART1 pads is 3V3).

### nRTS unused (no flow control)

For `getty` console use, no flow control needed. nRTS pin left floating. (Datasheet says no internal pull on nRTS — it's an output, will idle high when no flow control is active. Floating is safe.)

### Series resistors on TX/RX (defensive)

Add 33 Ω series on each line. Two reasons:
1. Edge-rate slowdown reduces EMI from sharp 3.3V CMOS edges over the few cm of trace.
2. Current limit if the user accidentally plugs in a 5V-tolerant FT232 dongle to the TTL header *while* CH340N is also driving — the 33Ω limits short-circuit current to ~100 mA, well under both chips' 50 mA per-pin spec.

### TTL header pinout

Standard FTDI-cable order: `GND, CTS, VCC, TX (host→DUT), RX (DUT→host), nRTS`. We're not using flow control, so 4-pin minimum: `GND, 3V3, TX_DUT_OUT, RX_DUT_IN`. Mark silkscreen carefully because pinout is not standardized across boards.

**Decision: 4-pin 2.54 mm header, GND / 3V3 / TX (i.MX→header) / RX (header→i.MX).** No flow control. Ferrite optional (skip for v0).

## Module API

```ato
module USBUart:
    power_5v   : ElectricPower      # in
    power_3v3  : ElectricPower      # for TTL header power pin
    uart       : UART_Base          # to MPU UART1 (tx, rx only)
```

## Reviewer findings (batch review 2026-05-04)

| Sev | Issue | Status |
|---|---|---|
| Critical | "CH340N pinout wrong" — reviewer cited CH340DS1 v3D | **FALSE POSITIVE** — verified against the WCH CH340DS1 v3D §3 (Pin Description) and CH340N SOP-8 diagram on page 1: auto-gen part has correct pinout (UD+=1, UD-=2, GND=3, RTS#=4, VCC=5, TXD=6, RXD=7, V3=8). Reviewer mis-cited the CH340G pinout as if it applied to CH340N. |
| High | VBUS tied to internal 5V_BOARD = backfeed risk | **FIXED** — only VBUS GND tied to 5V GND now; CH340N runs from 5V_BOARD directly |
| High | UART1 collides with i.MX boot-ROM Serial Download Protocol | **DOC FIX** — use UART2 in MPU pinmux for console, not UART1. UART1 reserved for SDP recovery. |
| Medium | 33Ω TX/RX series — fine for console, document | **NOTED** — at 1.5 Mbaud max, 33Ω × 10pF = 330 ps RC, negligible |
| Low | ESD on USB-C #3 line side | TODO — add TVS to USB connector wrapper |

## Open questions / TODOs

- [ ] Decide TTL header polarity printing on silkscreen.
- [ ] ESD on all USB-Cs (D+/D- + CC1/CC2): TVS array (e.g. NXP PESD3V3L4UF or USBLC6-2SC6).
- [ ] MPU module: pinmux UART2 not UART1.

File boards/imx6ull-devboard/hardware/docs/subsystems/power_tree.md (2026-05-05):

# Power tree subsystem

## Role

Convert 5V_BOARD (output of the input OR) into all the rails the i.MX 6ULL and peripherals consume.

## Architecture

```
5V_BOARD ──┬── TPS563201 buck → 3V3      (1A,  most NVCC_*, ETH PHY, audio, CH340N)
           ├── TPS563201 buck → 1V4      (600 mA, VDDARM_IN + VDDSOC_IN)
           ├── TPS563201 buck → 1V35     (400 mA, NVCC_DRAM for DDR3L)
           ├── LDK220 LDO    → 3V SNVS   (1 mA, VDD_SNVS_IN, with CR2032 backup)
           │
3V3 ──── TLV75901 LDO → 1V8              (300 mA, NVCC_SD card option, NVCC_NAND)
1V35 ──── TPS51200 → 0.675V VTT          (sink/source, DDR3L termination)
```

Three TPS563201 instances → one LCSC line item (commonization).

## i.MX 6ULL rail map

From `imx6ull-MCIMX6Y2CVM08AB-datasheet.pdf` §3.1 Power Supplies and §4.1 Chip-Level Conditions:

| Rail | i.MX pins | V | I (typ) | Source |
|---|---|---|---|---|
| VDD_SNVS_IN | SNVS supply | 2.8–3.3V | <1 mA | LDK220 + coin cell |
| VDD_HIGH_IN | high-voltage analog | 2.8–3.3V | low | 3V3 buck |
| VDDARM_IN | ARM core | 1.275–1.5V | up to 0.5A | 1V4 buck |
| VDDSOC_IN | SoC + GPU | 1.275–1.5V | up to 0.4A | 1V4 buck (same as ARM, allowed per datasheet) |
| NVCC_DRAM | DDR3L IO | 1.28–1.45V | up to 0.4A | 1V35 buck |
| NVCC_SD1 | SDcard IO | 1.65–1.95V or 2.7–3.6V | <100 mA | 1V8 LDO (or 3V3 — switch via PMIC; here just 1V8 for simplicity) |
| NVCC_ENET1 | Ethernet IO | 1.65–1.95V or 2.7–3.6V | <50 mA | 3V3 |
| NVCC_NAND, NVCC_JTAG, etc. | various | 3V3 | <50 mA each | 3V3 |
| USB_VBUS | USB OTG charge pump in | 4.0–5.5V | <10 mA | 5V_BOARD |

## First-principles design notes

### Why three instances of the same buck (TPS563201)

**Commonization.** TPS563201 spans 0.76–7V output, up to 3A — covers all three sub-5V rails (3V3, 1V4, 1V35) with one part in the BOM. Different feedback dividers per instance set the output voltage; everything else (compensation, inductor 2.2 µH, switching freq 580 kHz) is identical. Reduces JLC setup fee by 2× $3 vs three different bucks.

### Buck duty-cycle sanity check (first principles)

| Rail | Vin | Vout | Duty | Ton @ 580 kHz | TPS563201 Tmin (~110 ns) |
|---|---|---|---|---|---|
| 3V3 | 5V | 3.3V | 0.66 | 1138 ns | OK |
| 1V4 | 5V | 1.4V | 0.28 | 482 ns | OK |
| 1V35 | 5V | 1.35V | 0.27 | 466 ns | OK |

All three duty cycles produce Ton well above the controller minimum on-time. If we ever scale Vin up to 12V the 1V35 duty becomes 0.11 → Ton 194 ns, still OK but margins thin. For this design (5V input) we're comfortable.

### Why 1V8 from 3V3 LDO instead of dedicated buck

300 mA peak at 1.5V drop = **0.45 W** dissipation in the LDO. SOT-23-5 thermal limit is ~0.5 W. Marginal. Will derate — assume typical SD/eMMC traffic is 100 mA average, peak briefly at 300 mA. Could add a heat-spreading pour. A dedicated buck would save the dissipation but adds another inductor + 2× R + bulk caps + EN logic = more BOM, more area, more failure surface for a 0.45W problem.

**TODO:** confirm TLV75901 thermal pad is tied to GND copper pour; add 4–6 thermal vias to bottom plane.

### VTT termination — must be sink/source

DDR3L has bidirectional bus. VTT termination network (typ 39Ω to VTT on each DQ line) sinks current when the line is low and sources when high. A simple LDO can only source — it'll regulate when the bus is mostly high but lose voltage when the bus is mostly low. Need a sink/source like **TPS51200** (or SY56012 fallback). TPS51200 needs `ato create part` (not in registry).

VTT must be **VDDQ/2 = 0.675V** with VTTREF (separate output) supplying ~0.5% accurate reference for DDR3 receivers.

### VDD_SNVS — coin cell switchover

Always-on rail. Powers RTC + 4 KB secure RAM. Rule: keep board's VDD_SNVS at 3.0–3.3V when external power is present; switch to coin cell (2.5–3.3V) when bench/USB-C disconnected. **LDK220 + Schottky-OR with coin cell** is the standard. **TODO:** add the coin cell + Schottky in Debug subsystem.

### Power-on sequencing — known limitation

i.MX 6ULL datasheet §3.1 specifies: VDD_SNVS_IN → VDD_HIGH_IN → VDDARM/VDDSOC → NVCC_DRAM → POR_B release. Strict ordering helps avoid latch-up.

For prototype simplicity, all three TPS563201 EN pins are tied high via the package's default 10 kΩ pull-up to Vin → all bucks soft-start simultaneously. The 580 kHz buck soft-start (~1 ms) is much faster than i.MX's POR debounce (handled by the **TPS3808** or similar reset supervisor we'll add to Debug). The reset supervisor holds POR_B asserted until 3V3 is good — by which time all other rails have settled.

If first-article testing shows PoR-related failures, we'll revisit with proper PG-daisy-chain or RC delays on EN pins. **TODO: add TPS3808 to Debug subsystem.**

## Module API

```ato
module PowerTree:
    power_5v   : ElectricPower      # in
    power_3v3  : ElectricPower      # out
    power_1v4  : ElectricPower      # VDDARM/VDDSOC
    power_1v35 : ElectricPower      # NVCC_DRAM
    power_1v8  : ElectricPower      # SD/NAND IO option
    power_snvs : ElectricPower      # SNVS (3V)
    # power_vtt comes from a separate module wrapped around TPS51200, fed from power_1v35
```

## Reviewer findings (2026-05-04 first pass)

| # | Sev | Issue | Status |
|---|---|---|---|
| 1 | Critical | SNVS not first-on (sequence violation) | **FIXED** — 470 nF EN-delay caps on each buck (RC ≈ 4.7 ms) ensure SNVS LDO settles before any buck soft-starts |
| 2 | Critical | Coin-cell OR missing (lost SNVS on 5V drop) | **FIXED** — moved into PowerTree as `vbat_in` interface + 2× SS34 OR diodes; coin cell + 1k limit live in Debug feeding `vbat_in` |
| 3 | High | NVCC_DRAM ripple/setpoint margin | **PARTIAL** — added ferrite bead + 22 µF bulk on buck output; tightened setpoint to ±4%. FB ripple-injection network deferred to upstream PR on `atopile/ti-tps563201`. |
| 4 | High | Inductor 3.1 A < 5.5 A OCL peak | **FIXED** — `assert inductor.saturation_current >= 4.5A` on all 3 bucks; picker chose SXN SMNR5030-2R2N (4.5A) |
| 5 | High | Doc claimed SOT-23-5 but BOM is WSON-6 | **FIXED** — doc updated below |
| 6 | High | Shared VDDARM/VDDSOC, no bead | **FIXED** — split into `power_1v4_arm` and `power_1v4_soc` with ferrite bead between, local 10 µF + 100 nF on SoC side |
| 7 | Medium | No 5V inrush control | **DEFERRED** — owned by Power Input subsystem (load switch) |
| 8 | Medium | No PG; supervisor is TODO | **DEFERRED** — Debug subsystem (TPS3839 multi-input supervisor) |
| 9 | Low | FB divider current bound too loose | **DEFERRED** — needs upstream `atopile/ti-tps563201` PR |
| 10 | Low | X5R temp derating not in doc | **NOTED** below |

### #5 corrected: TLV75901 is WSON-6

Picker selects **TLV75901PDRVR** (WSON-6 with thermal EP), not SOT-23-5 as originally documented. WSON-6 with proper thermal-via array on EP gives θJA ≈ 45 °C/W. At 0.45 W worst case, ΔT ≈ 20 °C → die at ~90 °C with 70 °C ambient. **Layout requirement: ≥4 vias on EP to GND plane.**

### #10 X5R derating note

Picked output caps are 10 µF X5R 25V 0805. Combined derating:
- DC bias at 1.35V: ~−2% → 9.83 µF effective
- X5R at +85°C: ~−15% → 8.36 µF effective
- 3 caps in parallel = 25 µF worst-case (≈ 30 µF nominal)

Within TPS563201's 20–68 µF window, but at the lower edge. Adding the post-ferrite 22 µF bulk takes us to ~47 µF total — comfortably mid-window.

## Still open / TODOs

- [ ] `ato create part` for TPS51200 (VTT termination) — not in registry. → DDR3 subsystem.
- [ ] Add multi-input reset supervisor (TPS3839 watching 3V3 + 1V4 + 1V35) → Debug subsystem.
- [ ] Coin cell + 1 kΩ charge limit → Debug subsystem (feeds `psu.vbat_in`).
- [ ] Layout: TLV75901 EP needs ≥4 GND vias.
- [ ] Layout: ferrite bead placement at the "boundary" between buck and consumer pour.
- [ ] Upstream PR on `atopile/ti-tps563201`: add FB ripple-injection R/C option for all-ceramic outputs.
- [ ] Upstream PR on `atopile/ti-tps563201`: tighten `feedback_divider.current` to 50–200 µA range.
- [ ] Decide separate 3V3_ANALOG ferrite split for LAN8742A VDDA (Issue 5 from Ethernet review).

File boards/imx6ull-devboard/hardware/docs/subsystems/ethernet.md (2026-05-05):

# Ethernet subsystem

## Role

10/100 Mbps Ethernet so the board can join the home LAN, accept SSH, and serve TFTP/NFS during firmware bring-up.

## Architecture

```
MPU ENET1 (RMII) ── LAN8742A PHY ── magnetics (in RJ45) ── twisted pair
MPU MDIO ─────────── LAN8742A SMI
LAN8742A → 2× LED ── front panel link/activity
```

Single-chip 10/100 PHY, RMII (saves pins vs MII), no external switch. i.MX 6ULL has two ENET MAC cores; we use ENET1 only (ENET2 reserved for future / debug).

## Part choices

| Role | Part | LCSC | Cite |
|---|---|---|---|
| PHY | Microchip LAN8742A-CZ-TR | C621424 | LAN8742A datasheet |
| PHY package | atopile/microchip-lan8742a v0.3.0 | — | Pre-built atopile module — handles RBIAS, decoupling, crystal, straps. **Best canonical example in the registry.** |
| RJ45 + magnetics | HanRun HR911105A | C12074 | HR911105A datasheet |
| Crystal | (provided by atopile package) Yangxing X322525MRB4SI 25 MHz | (in pkg) | The atopile package bundles this. |

## First-principles design notes

### Why LAN8742A (not LAN8720A)

Both are pin-compatible 10/100 RMII PHYs. LAN8742A is **already packaged** in atopile (saves a multi-day `ato create part` for a 24-pin QFN), it has a built-in 1.2 V regulator (saves an external LDO), and it's stocked at JLC (3,774 units). LAN8720A would shave $0.30 off BOM but cost a week of effort. **Take the win.**

### Why single-chip, no external switch

Board is a dev/learning platform. Single port suffices for SSH + TFTP. A switch (e.g., RTL8305NB) would cost +1 IC, +N magnetics, +N RJ45s, +routing. Out of scope.

### RBIAS = 12.1 kΩ ±1%

Set by the LAN8742A datasheet as a precision bias for the internal current sources that drive the MDI pairs. Critical — wrong value = wrong line drive amplitude = link partner can't decode. Atopile package already encodes this.

### Crystal = 25 MHz, ⚠️ load caps are wrong upstream

LAN8742A wants 25.000 MHz ±50 ppm with crystal CL = 18 pF. The math for parallel-resonance load caps is:

```
CL = (Cload_left × Cload_right) / (Cload_left + Cload_right) + Cstray_per_leg
18 = Cload/2 + Cstray
Cload = 2 × (18 - Cstray) ≈ 24 to 30 pF (for Cstray = 3 to 6 pF/leg)
```

So each load cap should be **~27 pF**, not 18 pF.

**Bug in upstream `atopile/microchip-lan8742a@0.3.0`:** sets load caps to 18 pF (= the crystal's CL value, not the calculated load cap). This pulls the oscillator high by tens of ppm and risks blowing the ±50 ppm budget.

**Status:** can't override in our wrapper (atopile constraints are additive, not replacing). TODO: fork the package or file a PR upstream. For prototype boards we may live with a few extra ppm of clock offset; for production, fix.

### MDI termination strategy

LAN8742A drives current-mode into the magnetics. The package routes to `ethernet.pairs[0]` (RX) and `ethernet.pairs[1]` (TX) `DifferentialPair` — these go to the magnetics center taps + outputs. The center-tap caps (typically 2× 10 nF + 1 nF Bob Smith resistor network to chassis ground) are **not** in the LAN8742A package — we add them externally on the magnetics side. **TODO:** wire the magnetics + Bob Smith network in the Network wrapper.

### Bob Smith termination

For each unused pair (4-pin RJ45 in our case has 2 used, 2 unused) and the center-taps, the standard EMI termination is 75 Ω + 1 nF to chassis. Datasheet of HR911105A shows the recommended network. **TODO:** add when we wrap the RJ45.

### LED count

Two LEDs out of LAN8742A: link (ETH_LED1) + speed (ETH_LED2). Both routed to the RJ45 jack (HR911105A has integrated LEDs in the bezel — saves 2 board LEDs).

## Module API (provided to Board)

```ato
module Network:
    power_3v3 : ElectricPower      # rail in
    rmii       : RMII              # to MPU ENET1
    mdio       : MDIO              # to MPU
    reset      : ElectricLogic     # active-low, MPU drives
```

## Reviewer findings (2026-05-04 first pass)

Independent reviewer agent caught critical bugs in the upstream `atopile/microchip-lan8742a@0.3.0` package and our initial wrapper. Status:

| # | Severity | Issue | Status |
|---|---|---|---|
| 1 | **Critical** | nINTSEL strap missing pulldown — PHY latches nINTSEL=1, no REF_CLK to MAC | **FIXED** in `network.ato` (4.75kΩ pulldown) |
| 2 | **Critical** | MDI termination missing — 4× 49.9Ω TXP/TXN/RXP/RXN to VDDA per Microchip Checklist | **FIXED** in `network.ato` |
| 3 | High | HR911105A magnetics + Bob Smith + Y-cap to chassis | TODO — wrap when we add magjack |
| 4 | High | Crystal load caps wrong upstream (18pF should be ~27pF) | **DEFERRED** — can't override in wrapper. File upstream PR. |
| 5 | Medium | VDDA ferrite-bead split + 22nF RXCT cap | TODO — same wrapper |
| 6 | Medium | LED1/LED2 wiring polarity affects REGOFF strap | TODO — handle in Debug subsystem |
| 7 | Medium | i.MX RMII pad pull-config at boot must be high-Z (else fights MODE straps) | Note for MPU module |
| 8 | Medium | ESD protection on RJ45 cable side | TODO — same wrapper |
| 9 | Low | MDC pull-up unnecessary — push-pull MAC-driven | **FIXED** (removed) |
| 10 | None | Reset signal verified OK | — |

## Other open TODOs

- [ ] HR911105A magjack: build the wrapper (Bob Smith + ESD + bezel LEDs)
- [ ] File upstream PR on atopile/microchip-lan8742a for crystal cap value + missing termination
- [ ] Confirm i.MX 6ULL ENET1 RMII pad PUE=0 at reset in MPU pinmux

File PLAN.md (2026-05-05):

# Plan & Decision Log

Living document. Captures *why* each choice was made so future-me (or a future agent) can re-evaluate when something breaks.

## Known blocker (2026-05-04): atopile picker contradiction on TPS563201 FB divider

**Symptom:** `ato build` fails with `Contradiction: No candidate assignment satisfies the discrete problem system` on `Board.psu.buck_3v3.feedback_divider.chain.resistors[0/1].resistance`. Build worked when only Ethernet + PowerTree were instantiated; fails after adding MPU module.

**Root constraint chain (verified by reading faebryk source):**

`/Users/frankwalsh/.local/share/uv/tools/atopile/lib/python3.14/site-packages/faebryk/library/`:

- `AdjustableRegulator.py` lines 85-95: binds `feedback_divider.v_in = output_voltage = power_out.voltage` and `feedback_divider.v_out = reference_voltage`.
- `ResistorVoltageDivider.py` lines 133-148 (`_ratio_eq`): asserts `R[1]/(R[0]+R[1]) = v_out/v_in`. So R values fully determine `power_out.voltage` given `reference_voltage`.
- TI_TPS563201 package: `assert reference_voltage within 0.768V +/- 0.1%`.

**What I tried (all failed identically):**

1. ±5%, ±7%, ±10% tolerance on `buck.output_voltage` assertion
2. Pin R values directly: `resistance = 33kohm +/- 1%` and `10kohm +/- 1%`
3. Pin `feedback_divider.current = 76uA +/- 30%`
4. Pin `feedback_divider.total_resistance = 50kohm +/- 50%`
5. **Diagnostic:** comment out 2 of 3 bucks → still fails on the remaining one
6. Pin `lcsc_id = "C25817"` (33kΩ UNI-ROYAL) → "No matching component found" — atopile's part DB doesn't carry C25817

**What I haven't tried (concrete next steps to resume):**

- **Read `faebryk.core.solver.DiscreteSystem`** to understand candidate generation. The error message names R[0]/R[1] as the contradiction site but doesn't say *which* upstream constraint propagated to make their joint domain empty.
- **Find a 33kΩ 0402 1% LCSC ID that IS in atopile's part DB** — `ato create part` interactive command crashes (OSError); need to drive it via `--search` non-interactively with various candidate C-numbers (FOJAN, YAGEO, BOURNS, KOA), or add the part manually.
- **Fork `atopile/ti-tps563201`** — copy package into our `parts/` directory, remove the `feedback_divider`-from-`AdjustableRegulator` inheritance, hand-wire R values + footprint refs.
- **Replace AdjustableRegulator entirely** — wrap our own buck module from scratch using stdlib `MOSFET` + `Inductor` + `Capacitor` and explicit `ResistorVoltageDivider` we control, without any inherited solver coupling.

**Likely-correct hypothesis:** the JLC 0402 1% catalog atopile's picker draws from has a discrete set of values; with all the new MPU consumer constraints loaded into `power_3v3.voltage`, no R pair satisfies the joint domain even with ±10% tolerance. But this is a guess — the contradiction message doesn't expose the constraint set. Need solver source-reading to confirm.

**Status:** all 7 subsystems (Power Input, Power Tree, Ethernet, USB-UART, Audio, microSD, Debug) are ready. MPU module is ready and pinmux-verified against datasheet + EVK DTS. Top-level Board wires everything together. Build only blocks at the picker for FB resistors.

## Thesis

Be the first public end-to-end open-stack agent flow that ships a DDR-class Linux dev board, all the way to a shell prompt over the network. Quilter has done DDR closed-source/physics-based; atopile/tscircuit/Diode have done open-source LLM but stayed on 2-layer ESP32 boards. The novel contribution is the open intersection.

## Key decisions

### MPU: NXP i.MX 6ULL
**Why:** 0.8 mm pitch BGA-289 is the most forgiving DDR-capable BGA, ~$5–6 at qty 10, best-in-class open-source ecosystem (Olimex, Variscite reference designs), DDR3 instead of LPDDR4 means 4-layer is feasible.
**Considered & rejected:**
- STM32MP135 — TFBGA-289 0.5 mm pitch, harder fanout, thinner LCSC stock
- Allwinner T113-S3 — QFP-128 is *too* easy; skipping BGA defeats the blog-post premise
- i.MX 8M Mini — LPDDR4 + 6–8 layer HDI puts it out of open-stack reach

### DDR: DDR3L 16-bit, single chip
**Why:** Single-chip DDR3 dodges fly-by topology length-matching across multiple devices. 16-bit (vs 32-bit) halves the byte-lane routing burden. DDR3L (1.35 V) matches i.MX 6ULL native rails.
**Open:** Exact part TBD — query jlcparts for in-stock 256/512 MB ×16 DDR3L.

### Ethernet PHY: LAN8720A (likely)
**Why:** RMII, 3.3 V, sub-$1, JLC-stocked, used in 80% of i.MX 6ULL reference designs. KSZ8081 is the alternative if LAN8720A is out.

### Audio: MAX98357A I²S Class-D
**Why:** 3.2 W mono, integrated DAC, no external clock, $2 on LCSC, datasheet is short enough to fit fully in context. Output filter is a great ngspice teaching example for the blog.

### USB-UART: CH340N onboard
**Why:** JLC Basic part, SOP-8, ~$0.30. Beats requiring a USB-TTL dongle. Backup: 4-pin 0.1" header on the same UART for native access.

### Power input: USB-C PD sink + bench supply, OR'd

**Two-source manual-select OR** — never both connected simultaneously, so two Schottkys are safe (no current-hogging concern).

```
USB-C ── HUSB238 (5V fixed) ── SS54 ─┐
                                     ├── 5V_BOARD → discrete buck/LDO chain
Bench ── P-FET (rev-pol) ──────── SS54 ─┘
```

USB-OTG VBUS is *not* part of this OR — host mode = we source it; device mode = it powers us, others off.

| Role | Pick | LCSC | JLC | Notes |
|---|---|---|---|---|
| USB-C 16-pin USB2.0 | Korean Hroparts TYPE-C-31-M-17 | C2765186 | Basic | Canonical JLC-friendly |
| USB-C PD sink (5V R-strap) | Hynetek HUSB238 | C2829277 | Extended ($3 fee) | No Basic alternative; CC1/CC2 5.1kΩ pulldowns mandatory |
| OR Schottky ×2, 5A | SS54 | C22452 | Basic | ~0.55V drop @ 5A; bucks see ~4.5V min, fine |
| P-FET reverse-pol | AO3401A | C15127 | Basic | $0.02, Rds(on) 50 mΩ, SOT-23 |
| Bench terminal block, 5mm 10A | Ningbo Kangnex EK500V-5.0-02P | C8270 | Basic | 2-pin green screw |

**Note:** initial C-numbers were unverified. Live JLC sweep done — see `boards/imx6ull-devboard/hardware/BOM.md` for the verified BoM with corrections (HUSB238 was wrong, terminal block was wrong) and stock/fee reality check.

### Discrete buck/LDO power tree from 5V_BOARD

PMIC choice: **none.** Discrete chain. Bench-supply spec (32V/3.2A) gives unlimited headroom; even if we go to a higher input later we don't change the topology.

| Rail | V | Approx I | Stage | Candidate | atopile pkg |
|---|---|---|---|---|---|
| `VDD_ARM_SOC` | 1.4V | ~600 mA | buck from 5V | TPS62933 / TPS563201 | `atopile/ti-tps563201` |
| `NVCC_DRAM` | 1.35V (DDR3L) | ~400 mA | buck | TPS563201 | `atopile/ti-tps563201` |
| `VTT_DRAM` | 0.675V | tracked | sink/source LDO | TPS51200 | `ato create part` |
| `VDD_3V3` | 3.3V | ~1 A | buck | TPS54560x | `atopile/ti-tps54560x` |
| `VDD_1V8` | 1.8V | ~300 mA | LDO from 3V3 | TLV75901 | `atopile/ti-tlv75901` |
| `VDD_SNVS` | 3V | ~1 mA | LDO + coin cell | LDK220 | `atopile/st-ldk220` |

**Sequencing:** i.MX 6ULL requires VDD_SOC_IN before VDD_ARM_IN before NVCC_DRAM (RM ch. "Power Management" / AN5187). Open-drain power-good daisy-chain across regulators is the discrete trick — each stage's PG enables the next.

### Boot: SD primary + USB serial-download recovery
**Why:** i.MX 6ULL boot ROM supports USB serial download via NXP `uuu` / `imx_usb_loader` — you can recover a bricked board over the same USB-OTG port without ever needing JTAG. SD is the working boot medium; eMMC/QSPI is a stretch goal.

### Layers: 4-layer (Sig / GND / PWR / Sig)
**Why:** Cheapest stackup that still gives DDR3 a continuous reference plane. 6-layer is the safer call; 4-layer is the riskier "can we?" answer that makes the blog post interesting.

### Build system: Buildroot, not Yocto
**Why:** Single defconfig file = LLM-friendly. Yocto's layer system is brutal to reason about. Yocto wins for production; Buildroot wins for one-off boards and learning.

### LLM: Opus 4.7 (1M ctx) + Sonnet 4.6
**Why:** Opus for layout review, DDR rule generation, datasheet synthesis where errors are expensive. Sonnet for cheap iterative Q&A during firmware bring-up. Prompt-cache the i.MX 6ULL Datasheet + HDG (~300k tokens) as always-on context; RAG the 5000-page Reference Manual.

## Phase plan

1. **Repo + RAG** — scaffold, ingest datasheets with Docling, stand up FastMCP datasheet server.
2. **Block diagram + atopile skeleton** — mermaid power tree + peripheral diagram, top-level `.ato` module.
3. **Schematic capture** — PMIC, DDR3, MPU, Ethernet, USB, audio, UART, SD, JTAG modules. Resolve all parts via `pick_part`.
4. **Layout** — placement, BGA escape, DDR3 length-matching constraints (agent generates KiCad custom rules), Ethernet diff pairs, Freerouting on remaining nets.
5. **DRC clean + fab** — Gerbers, BOM, CPL, JLCPCB API quote.
6. **Bring-up** — UART → U-Boot → SD boot → Linux mainline + Buildroot rootfs.
7. **Network** — SSH over LAN.
8. **Audio demo** — `aplay sine.wav`.
9. **Post-mortem & blog**.

## Open questions

- PMIC choice: PCA9450 (newer) vs PF3000 (more references). Pending JLC stock check.
- DDR3 vendor: Nanya is JLC-friendly, Micron has better open IBIS models. Probably Nanya.
- 4-layer vs 6-layer — defer until DDR3 routing constraints are written; if the agent can't get a clean reference plane on 4, escalate.
- Closed-loop sim → schematic iteration: aspirational. May ship as "agent reads ngspice output and proposes a cap value" without full closure.
- Whether to write our own KiCad MCP or use Seeed's. Default: use Seeed, fork if needed.

## Non-goals

- Production-grade certifications (FCC/CE).
- Yocto, real-time kernel, secure boot.
- DDR4 / LPDDR4. The point is to make DDR3 work *on an open stack*, not push the SI envelope.
- Pretty silkscreen art. The blog post is the deliverable; the board is the proof.

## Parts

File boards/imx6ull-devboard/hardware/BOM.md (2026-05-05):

# Bill of Materials — i.MX 6ULL Dev Board v0

Verified against JLCPCB / LCSC May 2026 (see commit history for sweep date). **Re-verify Basic/Preferred status before order — JLC rotates these monthly.**

## Active components

| # | Role | MPN | LCSC | JLC | Stock | Qty-10 |
|---|---|---|---|---|---|---|
| 1 | MPU | NXP MCIMX6Y2CVM08AB | C414042 | Extended | 20,362 | $9.88 |
| 2 | DDR3L 2Gb ×16 | Nanya NT5CC128M16JR-EK | C428583 | Extended | **79** ⚠️ | $7.88 |
| 3 | Ethernet PHY 10/100 RMII | Microchip LAN8742A-CZ-TR | C621424 | Extended | 3,774 | $1.31 |
| 4 | RJ45 + magnetics | HanRun HR911105A | C12074 | Extended | 65,949 | $1.31 |
| 5 | USB-C 16-pin USB2.0 (×2) | TYPE-C 16PIN 2MD(073) SHOU HAN | C2765186 | Extended | 799,010 | $0.066 |
| 6 | USB-C PD sink | Hynetek HUSB238_002DD | **C7471904** | Extended | 9,191 | $0.39 |
| 7 | Schottky 5A OR (×2) | MDD SS54 | C22452 | **Basic** | 926,868 | $0.029 |
| 8 | P-FET SOT-23 (rev-pol) | AO3401A | C15127 | **Basic** | 1,366,313 | $0.047 |
| 9 | 5mm terminal block 2-pin | WJ128V-5.0-02P | ⚠️ C# unverified | likely Basic | — | ~$0.10 |
| 10 | Buck 3V3 / 1V4 / 1V35 (×3) | TI TPS563201DDCR | C116592 | Extended | 60,136 | $0.066 |
| 11 | DDR VTT term LDO | TI TPS51200DRCR | C34771 | Extended | **881** ⚠️ | $0.29 |
| 12 | LDO 1V8 300mA | TI TLV75901PDRVR | C544759 | Extended | 972 | ~$0.16 |
| 13 | RTC backup LDO | ST LDK220M-R | C443854 | Extended | 1,032 | $0.32 |
| 14 | I²S Class-D amp 3W | Maxim MAX98357AETE+T | C910544 | Extended | 11,595 | $1.17 |
| 15 | USB-UART bridge | WCH CH340N | C2977777 | Extended | 19,206 | $0.48 |
| 16 | microSD push-push | SOFNG TF-015 | C113206 | Extended | 13,387 | $0.14 |
| 17 | Cortex 10-pin 1.27mm hdr | Wcon 1310-1205G0M061CR02 | C721880 | unverified | — | — |
| 18 | CR2032 SMD holder | Q&J CR2032-BS-6-1 | C70377 | Extended | 26,926 | $0.13 |
| 19 | Reset tactile SMD | XKB TS-1187A-B-A-B | C318884 | **Basic** | 1,532,048 | $0.016 |
| 20 | 2-pos SMD DIP (BOOT_MODE) | kangshen DSIC02LSGET | C3293152 | unverified | — | — |

⚠️ = stock < 1000 or unverified — needs fallback or recheck before order.

## Backup substitutes (low-stock candidates)

| For | Substitute | LCSC | Reason |
|---|---|---|---|
| Nanya NT5CC128M16JR-EK | Micron MT41K128M16JT-125 | TBD | 79 units may not survive til order |
| TI TPS51200 | Silergy SY56012 | C155909 | 881 units |

## Assembly cost reality

- **3 of 20 lines are JLC Basic** (SS54, AO3401A, reset button). Everything else is Extended.
- **Extended setup fee:** ~$3 per unique part × ~17 = **~$51 in setup**.
- Unavoidable for a Linux-class board — no Basic version of MPU, PHY, PD sink, audio amp, USB-UART, etc.
- Total estimated PCBA setup cost (5 boards): **~$120–150** beyond per-board parts cost.

## Open verifications (do before submit)

1. **WJ128V-5.0-02P** — find correct C-number for the 2-pin variant. Original C8270 turned out to be 3-pin.
2. **Cortex JTAG header (#17)** — confirm JLC assembly assembles 1.27mm pitch SMD headers.
3. **DIP switch (#20)** — same.
4. **HUSB238 footprint** — C7471904 is the `_002DD` variant. Confirm the package matches what we'll generate via `ato create part`.
5. **Re-check JLC Basic/Preferred status** day-of-order — JLC rotates the list.

## Passives (TBD, will be solved at `ato build` time)

- Decoupling caps: 0402 X7R, 100 nF and 4.7 µF as needed
- Bulk caps: 47–100 µF / 10 V on 5V rail
- Power caps for buck regulators: per TPS563201 datasheet
- Pull-ups / pull-downs: 4.7 kΩ (I²C), 5.1 kΩ (USB-C CC), 12.1 kΩ (LAN8742A RBIAS), etc.
- LEDs: power-good, heartbeat, ETH link/act — generic 0603 red/green/blue

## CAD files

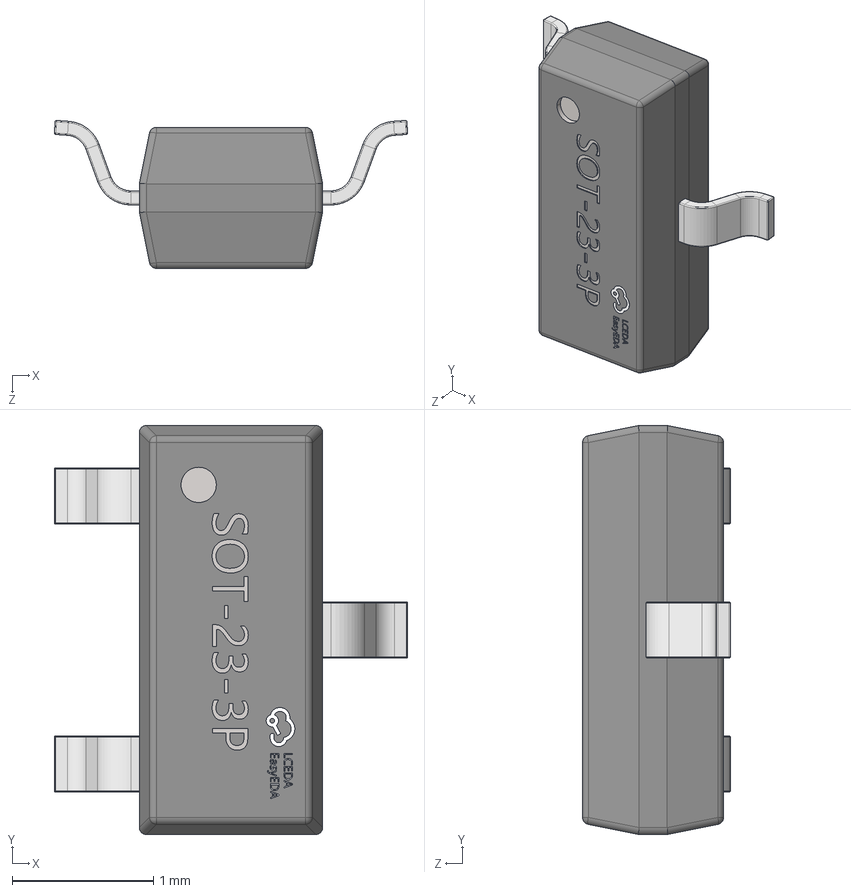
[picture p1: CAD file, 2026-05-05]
boards/imx6ull-devboard/hardware/src/parts/Alpha___Omega_Semicon_AO3401A/SOT-23-3P_L2.9-W1.3-H1.0-LS2.4-P0.95.step
2.51 x 2.90 x 1.05 mm

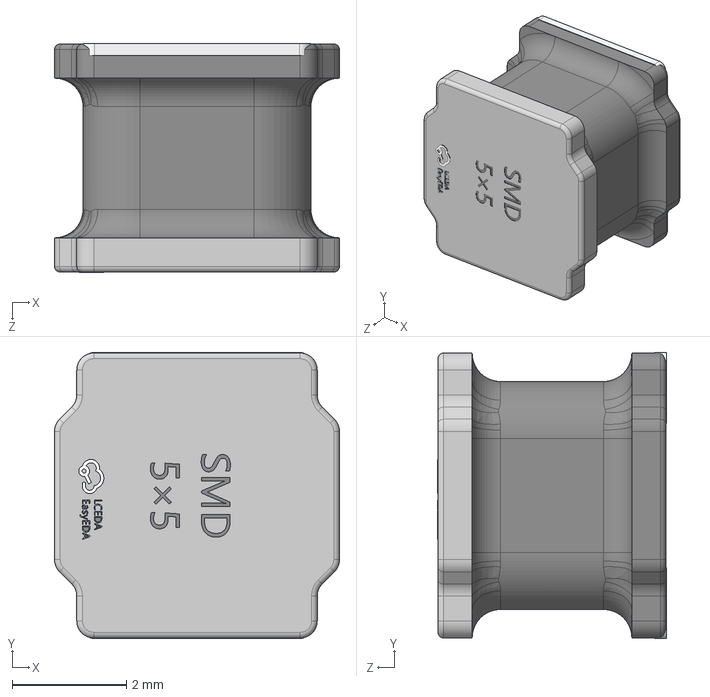
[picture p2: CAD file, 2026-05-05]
boards/imx6ull-devboard/hardware/src/parts/cjiang_FNR5020S2R2MT/IND-SMD_L5.0-W5.0-H4.0.step
5.00 x 5.02 x 4.02 mm

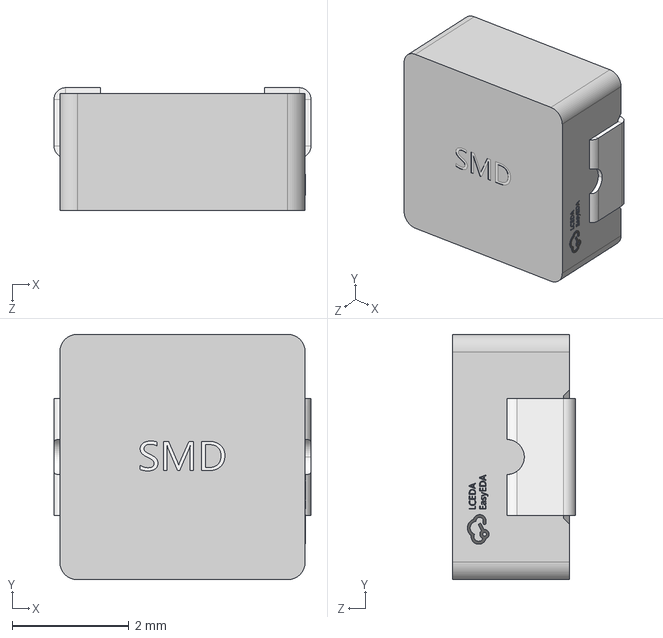
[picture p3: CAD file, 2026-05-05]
boards/imx6ull-devboard/hardware/src/parts/cjiang_FXL0420_2R2_M/IND-SMD_L4.2-W4.4-H2.0.step
4.40 x 4.20 x 2.10 mm

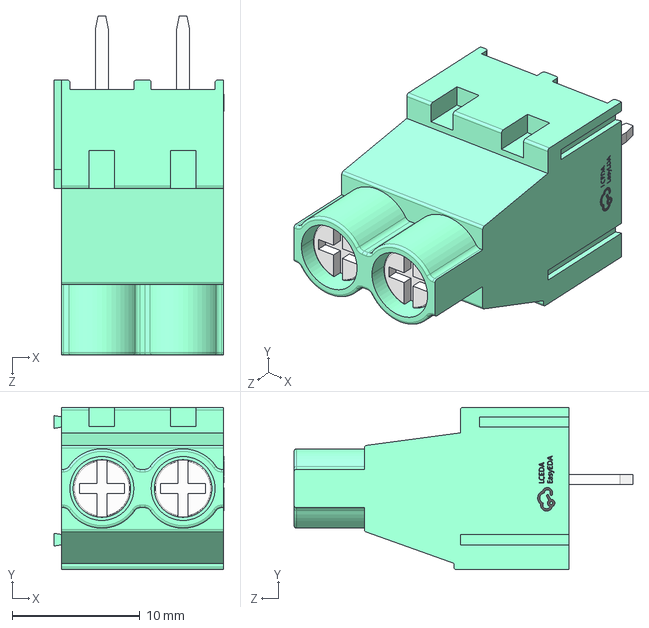
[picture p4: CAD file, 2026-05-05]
boards/imx6ull-devboard/hardware/src/parts/DIBO_DB910_6_35_2P_GN_S/CONN-TH_2P-P6.35_DB910-6.35-2P.step
13.3 x 12.7 x 26.5 mm

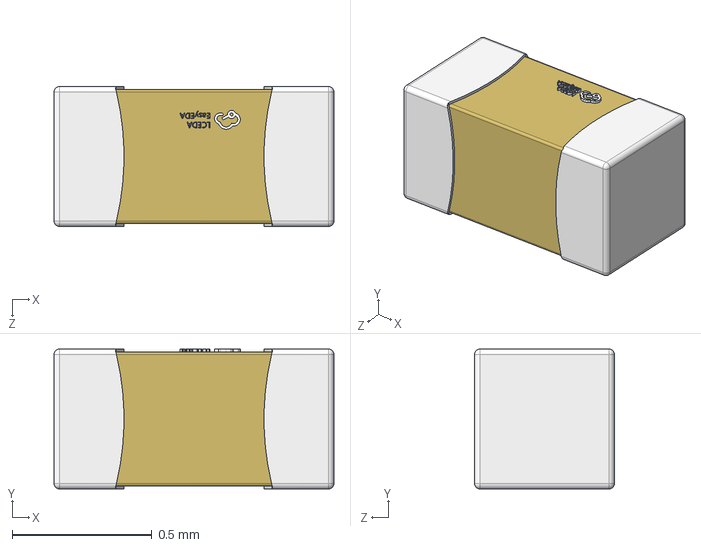
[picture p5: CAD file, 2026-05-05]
boards/imx6ull-devboard/hardware/src/parts/FH_0402CG220J500NT/C0402_L1.0-W0.5-H0.5.step
1.00 x 0.5 x 0.5 mm

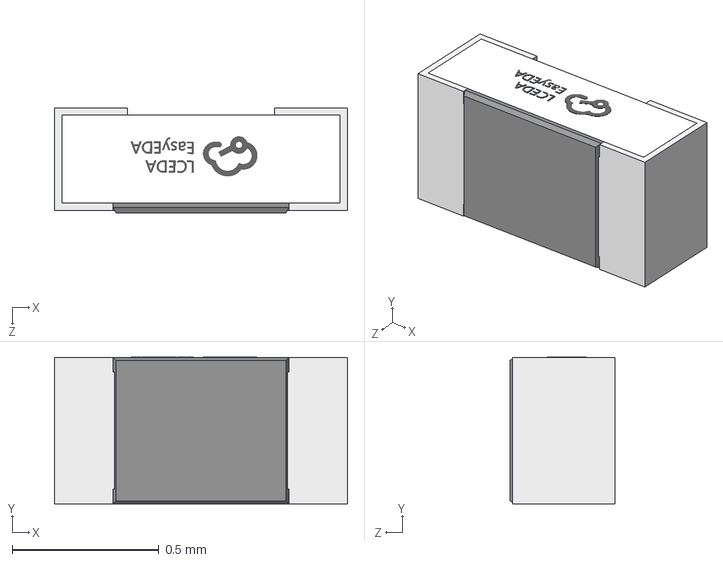
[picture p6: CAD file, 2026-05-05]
boards/imx6ull-devboard/hardware/src/parts/FOJAN_FRC0402F1332TS/R0402_L1.0-W0.5-H0.4.step
1.00 x 0.501 x 0.36 mm

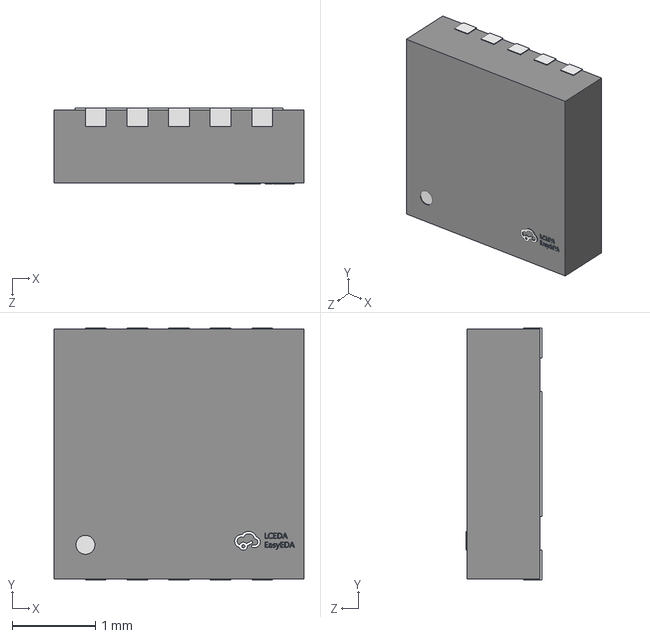
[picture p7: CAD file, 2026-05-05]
boards/imx6ull-devboard/hardware/src/parts/Hynetek_HUSB238_002DD/DFN-10_L3.0-W3.0-P0.50-BL-EP2.5.STEP
3.00 x 3.02 x 0.91 mm

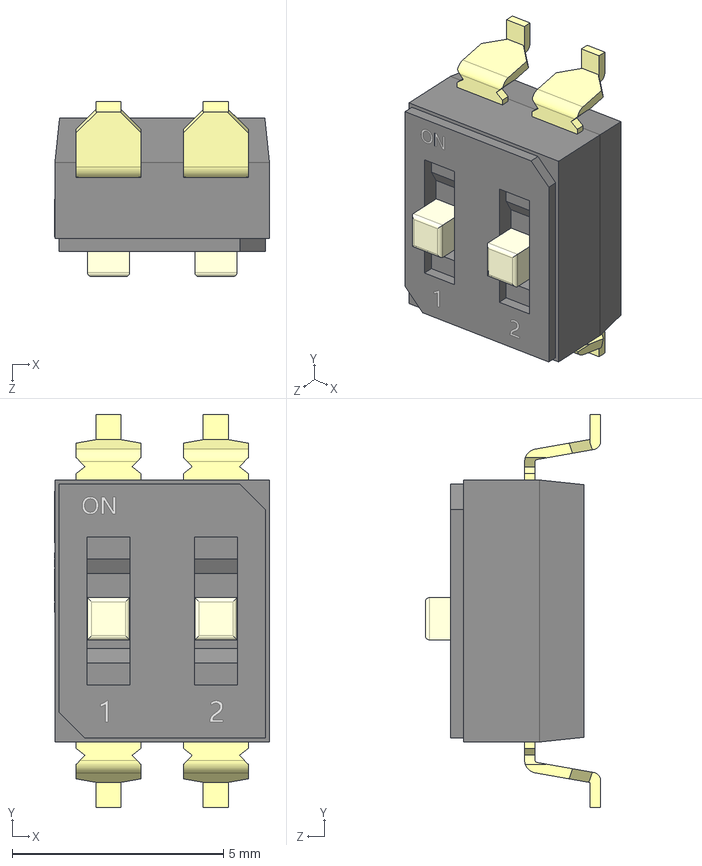
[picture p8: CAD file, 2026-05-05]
boards/imx6ull-devboard/hardware/src/parts/kangshen_DSIC02LSGET/SW-SMD_DSIC02LSGET.STEP
5.09 x 9.30 x 4.15 mm

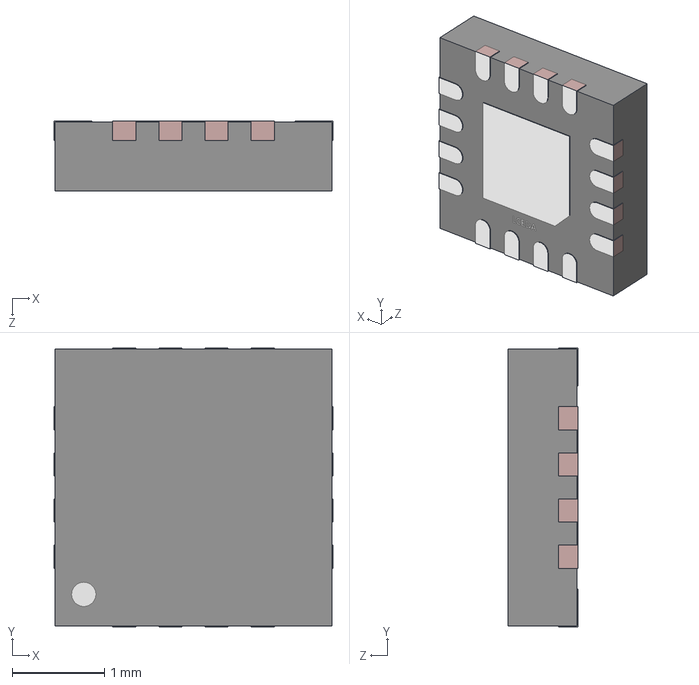
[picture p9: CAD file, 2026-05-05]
boards/imx6ull-devboard/hardware/src/parts/Maxim_Integrated_MAX98357AETE_T/TQFN-16_L3.0-W3.0-P0.50-BL-EP1.5.STEP
3.02 x 3.02 x 0.76 mm

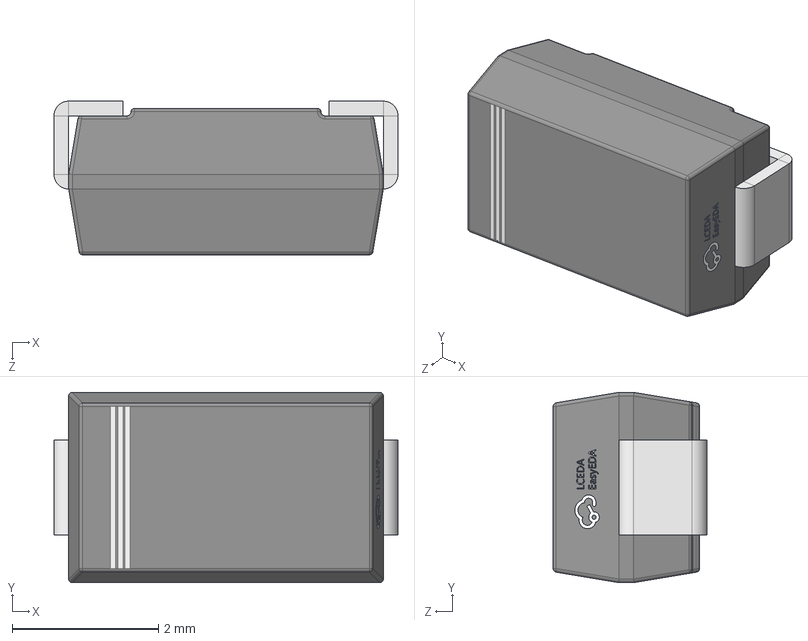
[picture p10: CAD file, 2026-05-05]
boards/imx6ull-devboard/hardware/src/parts/MDD_Microdiode_Electronics_SS34/SMA_L4.3-W2.6-LS5.2-RD.step
4.70 x 2.60 x 2.10 mm

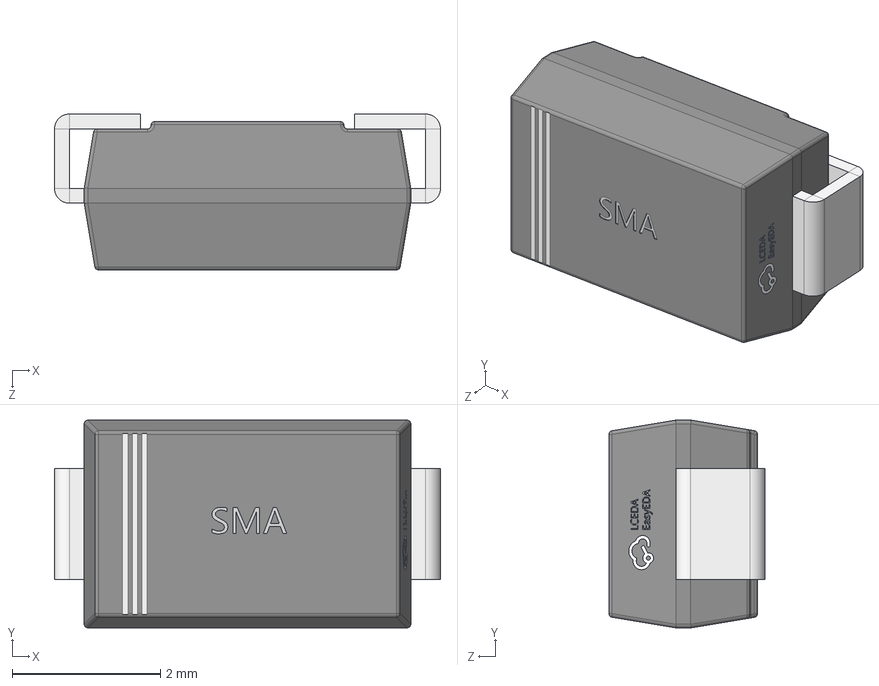
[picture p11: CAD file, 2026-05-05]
boards/imx6ull-devboard/hardware/src/parts/MDD_Microdiode_Electronics_SS54/SMA_L4.4-W2.8-LS5.4-R-RD.step
5.20 x 2.80 x 2.10 mm

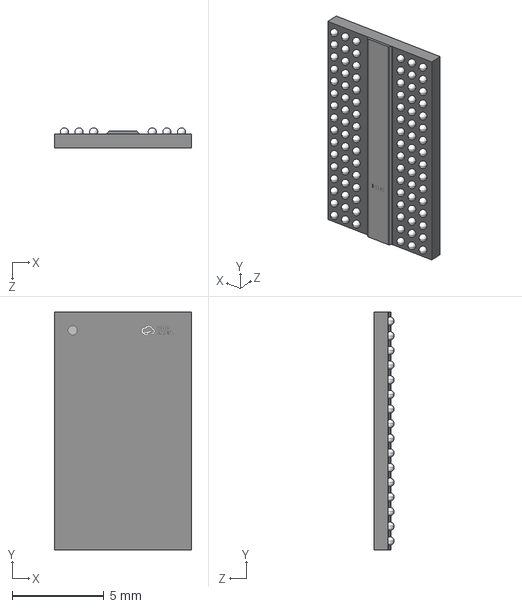
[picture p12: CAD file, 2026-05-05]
boards/imx6ull-devboard/hardware/src/parts/Nanya_Tech_NT5CC128M16JR_EK/TFBGA-96_L13.0-W7.5-H1.1-R16-C6-P0.80-TL.step
7.50 x 13.0 x 1.11 mm

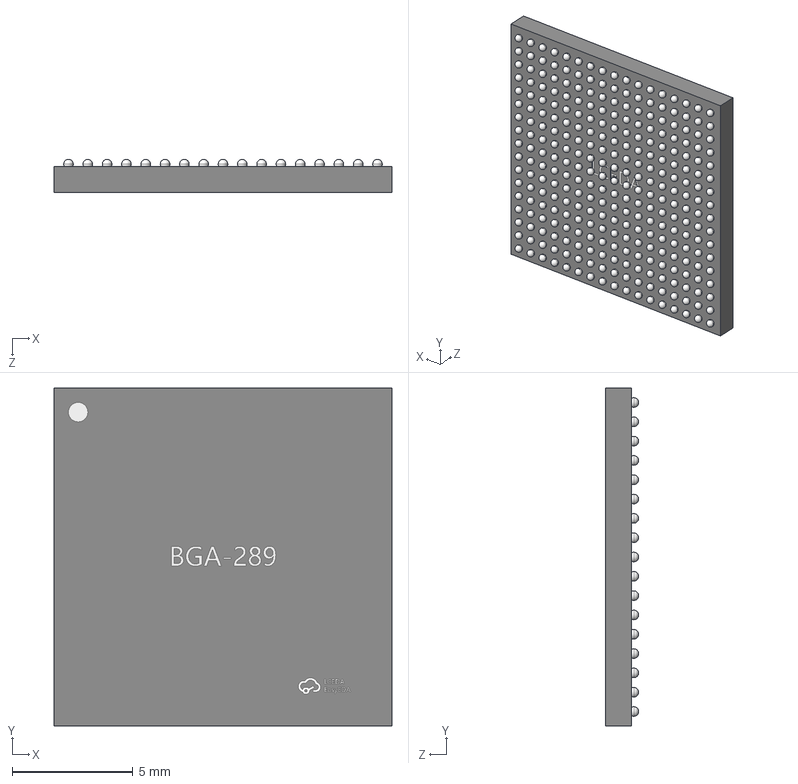
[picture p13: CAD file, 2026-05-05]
boards/imx6ull-devboard/hardware/src/parts/NXP_Semicon_MCIMX6Y2CVM08AB/BGA-289_L14.0-W14.0-H1.4-P0.8.step
14.0 x 14.0 x 1.38 mm

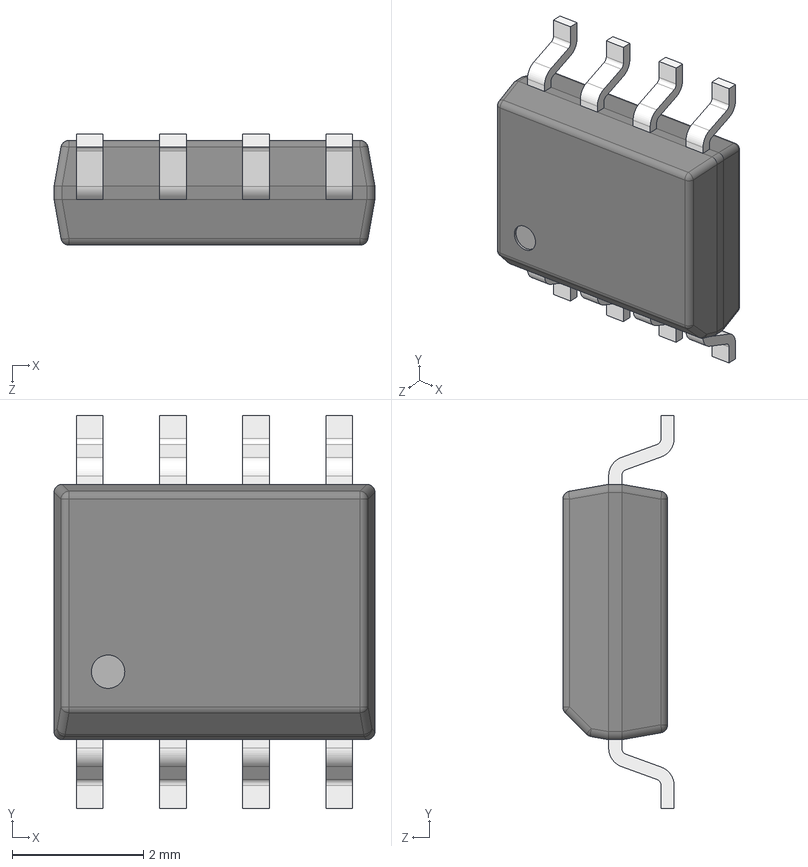
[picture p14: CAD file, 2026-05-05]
boards/imx6ull-devboard/hardware/src/parts/NXP_Semicon_PCF8563T_5_518/SOIC-8_L4.9-W3.9-H1.7-LS6.0-P1.27.STEP
4.90 x 6.00 x 1.70 mm

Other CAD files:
boards/imx6ull-devboard/hardware/src/parts/Q_J_CR2032_BS_6_1/BAT-SMD_L28.5-W16.0-H5.5-LS31.3_CR2032-BS-6-1.STEP
boards/imx6ull-devboard/hardware/src/parts/Samsung_Electro_Mechanics_CL21B102KBCNNNC/C0805_L2.0-W1.3-H1.3.step
boards/imx6ull-devboard/hardware/src/parts/SXN_SMNR5030_2R2N/IND-SMD_L5.0-W5.0-H1.2_SMNR5030.step
boards/imx6ull-devboard/hardware/src/parts/Samsung_Electro_Mechanics_CL31A107MQHNNNE/C1206_L3.2-W1.6-H1.3.step
boards/imx6ull-devboard/hardware/src/parts/Seiko_Epson_Q13FC13500004/FC-135R_L3.2-W1.5.STEP
boards/imx6ull-devboard/hardware/src/parts/Sunlord_GZ2012D601TF/R0805_L2.0-W1.3-H0.6.step
boards/imx6ull-devboard/hardware/src/parts/TECH_PUBLIC_SRV05_4/SOT-23-6_L2.9-W1.6-H1.5-LS2.8-P0.95.step
boards/imx6ull-devboard/hardware/src/parts/UNI_ROYAL_0603WAF1002T5E/R0603.STEP
boards/imx6ull-devboard/hardware/src/parts/WCH_CH340N/SOP-8_L4.9-W3.9-P1.27-LS6.0-BL-1.STEP
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

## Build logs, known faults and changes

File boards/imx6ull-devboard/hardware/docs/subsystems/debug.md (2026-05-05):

# Debug subsystem

## Role

Bring-up + dev workflow: poke at the board with JTAG, reset it, change boot mode, see what's happening via LEDs, keep the RTC alive over a power cycle, and break out the speaker + UART headers promised by Audio + USB-UART.

## Bag-of-stuff list

| Element | Component | LCSC | Why |
|---|---|---|---|
| JTAG/SWD 10-pin Cortex | Wcon 1310-1205G0M061CR02 (2×5 1.27mm SMD) | C721880 | Standard ARM debug header |
| Reset button | XKB TS-1187A-B-A-B (SMD tactile) | C318884 | JLC Basic, $0.016 |
| BOOT_MODE DIP | kangshen DSIC02LSGET (2-pos SMD) | C3293152 | Toggle SD ↔ USB serial-download |
| Status LEDs | stdlib `LEDIndicator` (2× 0603) | picker | Power good + heartbeat |
| CR2032 holder | Q&J CR2032-BS-6-1 (SMD) | C70377 | RTC backup battery |
| Charge-limit R | 1 kΩ stdlib | picker | Limits charge into non-rechargeable cell |
| OR Schottky | SS54 (commonized) | C22452 | Combined w/ LDK220 in PowerTree.vbat_in |
| 4-pin UART TTL header | atopile/pin-headers Male_2_54mm_1x4P_TH | (in pkg) | Console fallback |
| 2-pin speaker header | atopile/pin-headers Male_2_54mm_1x2P_TH | (in pkg) | MAX98357A output |

## First-principles design notes

### Reset button + RC debounce

i.MX 6ULL `POR_B` has internal pull-up + Schmitt input — minimal external help needed. We add:
- 10 kΩ external pull-up to 3V3 (deterministic deassertion)
- 100 nF debounce cap to GND (filters bounce on tactile button press)
- Tactile switch shorts POR_B to GND when pressed

### Cortex 10-pin pinout (industry standard)

```
 1 VTREF (3V3)     2 SWDIO/TMS
 3 GND             4 SWCLK/TCK
 5 GND             6 SWO/TDO
 7 KEY (nc)        8 NC/TDI
 9 GNDDetect      10 nSRST
```

i.MX 6ULL JTAG balls: `JTAG_TCK`, `JTAG_TMS`, `JTAG_TDO`, `JTAG_TDI`, `JTAG_TRSTB`, `POR_B`. We map:
- TMS → pin 2
- TCK → pin 4
- TDO → pin 6
- TDI → pin 8
- nSRST → pin 10 (also tied to POR_B / reset button net)
- 3V3 → pin 1 (target reference)
- GND → pins 3, 5, 9

`JTAG_TRSTB` is sometimes wired to pin 10 too (instead of nSRST), but most ARM probes drive nSRST. We tie `JTAG_TRSTB` to a 10 kΩ pull-up at the MPU (handled in MPU module) and don't expose it on the connector.

### BOOT_MODE strap

i.MX 6ULL boot ROM reads `BOOT_MODE[1:0]` at reset:
- `00` Internal fuses (production)
- `01` Serial download (USB-OTG / UART1) — recovery!
- `10` Internal boot (boot from BOOT_CFG straps — microSD in our case)

For dev work we want to toggle between **`10` (internal boot from microSD)** and **`01` (serial download recovery)**.

Implementation: BOOT_MODE0 = 1 (always), BOOT_MODE1 toggled by DIP switch:
- DIP closed → BOOT_MODE1 = 1 → `11` reserved (won't use)
- DIP open → BOOT_MODE1 = 0 → `01` (serial download)

Hmm — that's wrong. Need:
- `10`: BOOT_MODE1 = 1, BOOT_MODE0 = 0 → DIP1 high, DIP2 low
- `01`: BOOT_MODE1 = 0, BOOT_MODE0 = 1 → DIP1 low, DIP2 high

Two DIP switches naturally drive both bits. Using the kangshen DSIC02LSGET 2-position SMD DIP gives us 2× SPST. Each DIP-switch contact pulls its boot-mode signal to GND when CLOSED; default state via 10 kΩ pull-up to 3V3 = HIGH when OPEN.

Net mapping:
| DIP1 | DIP2 | BOOT_MODE1 | BOOT_MODE0 | Boot source |
|---|---|---|---|---|
| Open | Open | 1 | 1 | Reserved (avoid) |
| Closed | Open | 0 | 1 | Serial download (USB recovery) |
| Open | Closed | 1 | 0 | Internal boot (microSD) — **default** |
| Closed | Closed | 0 | 0 | Fuses (production) |

Default position label on silkscreen: "DIP1 OFF, DIP2 ON = SD boot."

### Status LEDs

Two onboard. More clutter than helpful.

- **3V3 PWR**: `LEDIndicator` directly on 3V3 rail. Stays on whenever board is powered.
- **HEARTBEAT**: Driven by an MPU GPIO; firmware pulses it once per second so you can see "yep, kernel is alive."

LED color: green for both (cheap, common, JLC Basic 0603 LEDs of green type are ~$0.005). Series resistor sized for 2 mA at 3V3 (low-current visible LED): R = (3.3 - 2.0) / 2e-3 = 650 Ω → use 680 Ω from common values.

`LEDIndicator` stdlib handles this — pass logic_in, power_in, plus optional active-low / use-MOSFET flags.

### Coin-cell + Schottky for VBAT_SNVS

PowerTree exposes `vbat_in: ElectricPower` for the SNVS coin-cell input. We feed it from:

- **CR2032 holder (Q&J CR2032-BS-6-1)** — 3V nominal, 220 mAh capacity.
- **1 kΩ charge-limit resistor** between cell + and the OR Schottky. CR2032 is a NON-rechargeable cell — the resistor protects against the i.MX SNVS rail back-driving current into it (max <100 µA reverse, well below the cell's tolerance for short pulses but still a no-no for long-term).
- **Schottky cathode at vbat_in.hv**, anode at the resistor. (Actually the OR is in PowerTree; we just feed `vbat_in` here with the cell + resistor + clean voltage.)

Net: Cell+ → 1 kΩ → vbat_in.hv (PowerTree handles the OR with LDK220 output).

When external power is on: SNVS rail = LDK220 output ≈ 3.0 V → Schottky path from cell is reverse-biased (cell at 3V, vbat_in at 3V → no current).

When external power off: LDK220 output drops to 0V → cell forward-biases its Schottky → vbat_in stays at 3V - 0.3V (Schottky drop) ≈ 2.7V which is still in SNVS spec.

### TTL UART + speaker headers

- 4-pin 2.54 mm: GND / 3V3 / TX (i.MX→header) / RX (header→i.MX), labeled on silkscreen.
- 2-pin 2.54 mm: speaker_p / speaker_n.

Both from the `atopile/pin-headers` package — saves us creating parts.

## Module API

```ato
module Debug:
    power_3v3        : ElectricPower
    power_5v         : ElectricPower    # for VBAT path? no — VBAT comes from cell directly
    vbat_to_psu      : ElectricPower    # → PowerTree.vbat_in

    # JTAG/SWD interface
    jtag             : JTAG             # to MPU JTAG pads

    # System
    reset            : ElectricLogic    # bidirectional: button or external probe → POR_B
    heartbeat        : ElectricLogic    # MPU GPIO → LED
    boot_mode0       : ElectricLogic    # to MPU BOOT_MODE0
    boot_mode1       : ElectricLogic    # to MPU BOOT_MODE1

    # Headers
    uart_console     : UART_Base        # 4-pin TTL header to MPU UART2 (parallel with CH340N)
    speaker_p        : Electrical
    speaker_n        : Electrical
```

## Open questions / TODOs

- [ ] Decide if we want a multi-input reset supervisor (TPS3839K33 or TLV803S) — defer to v2; rely on i.MX internal POR for v0.
- [ ] If first-article shows boot-mode confusion, swap DIP for a 4-pos rotary (boot-source selector with explicit positions).
- [ ] Layout: keep coin-cell trace short (low impedance for surge events).
- [ ] BOOT_CFG straps for SD slot configuration land in MPU module (need 6 strap resistors per i.MX 6ULL HDG §"Boot Configuration").

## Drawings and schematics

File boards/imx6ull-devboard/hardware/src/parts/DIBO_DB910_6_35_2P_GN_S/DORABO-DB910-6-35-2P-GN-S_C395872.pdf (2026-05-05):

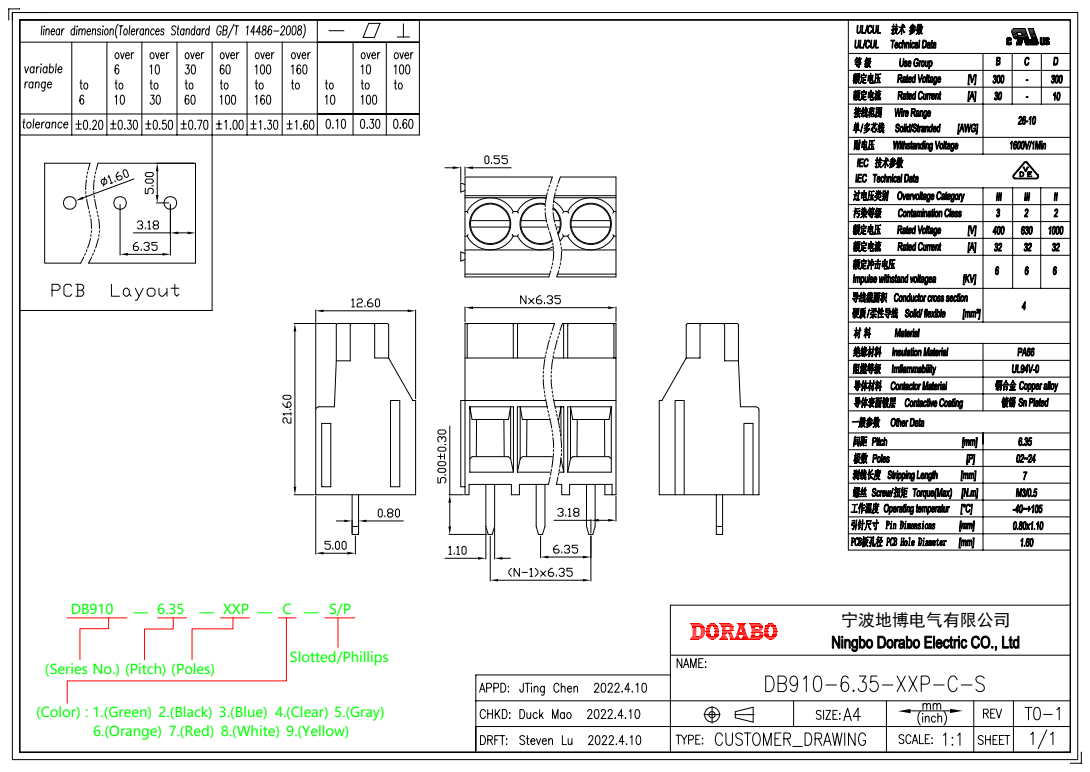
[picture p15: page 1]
— XXP; — S/P (Series No.) (Pitch) (Poles); Slotted/Phillips; 宁波地博电气有限公司

(Color) : 1.(Green) 2.(Black) 3.(Blue) 4.(Clear) 5.(Gray) 6.(Orange) 7.(Red) 8.(White) 9.(Yellow) DB910

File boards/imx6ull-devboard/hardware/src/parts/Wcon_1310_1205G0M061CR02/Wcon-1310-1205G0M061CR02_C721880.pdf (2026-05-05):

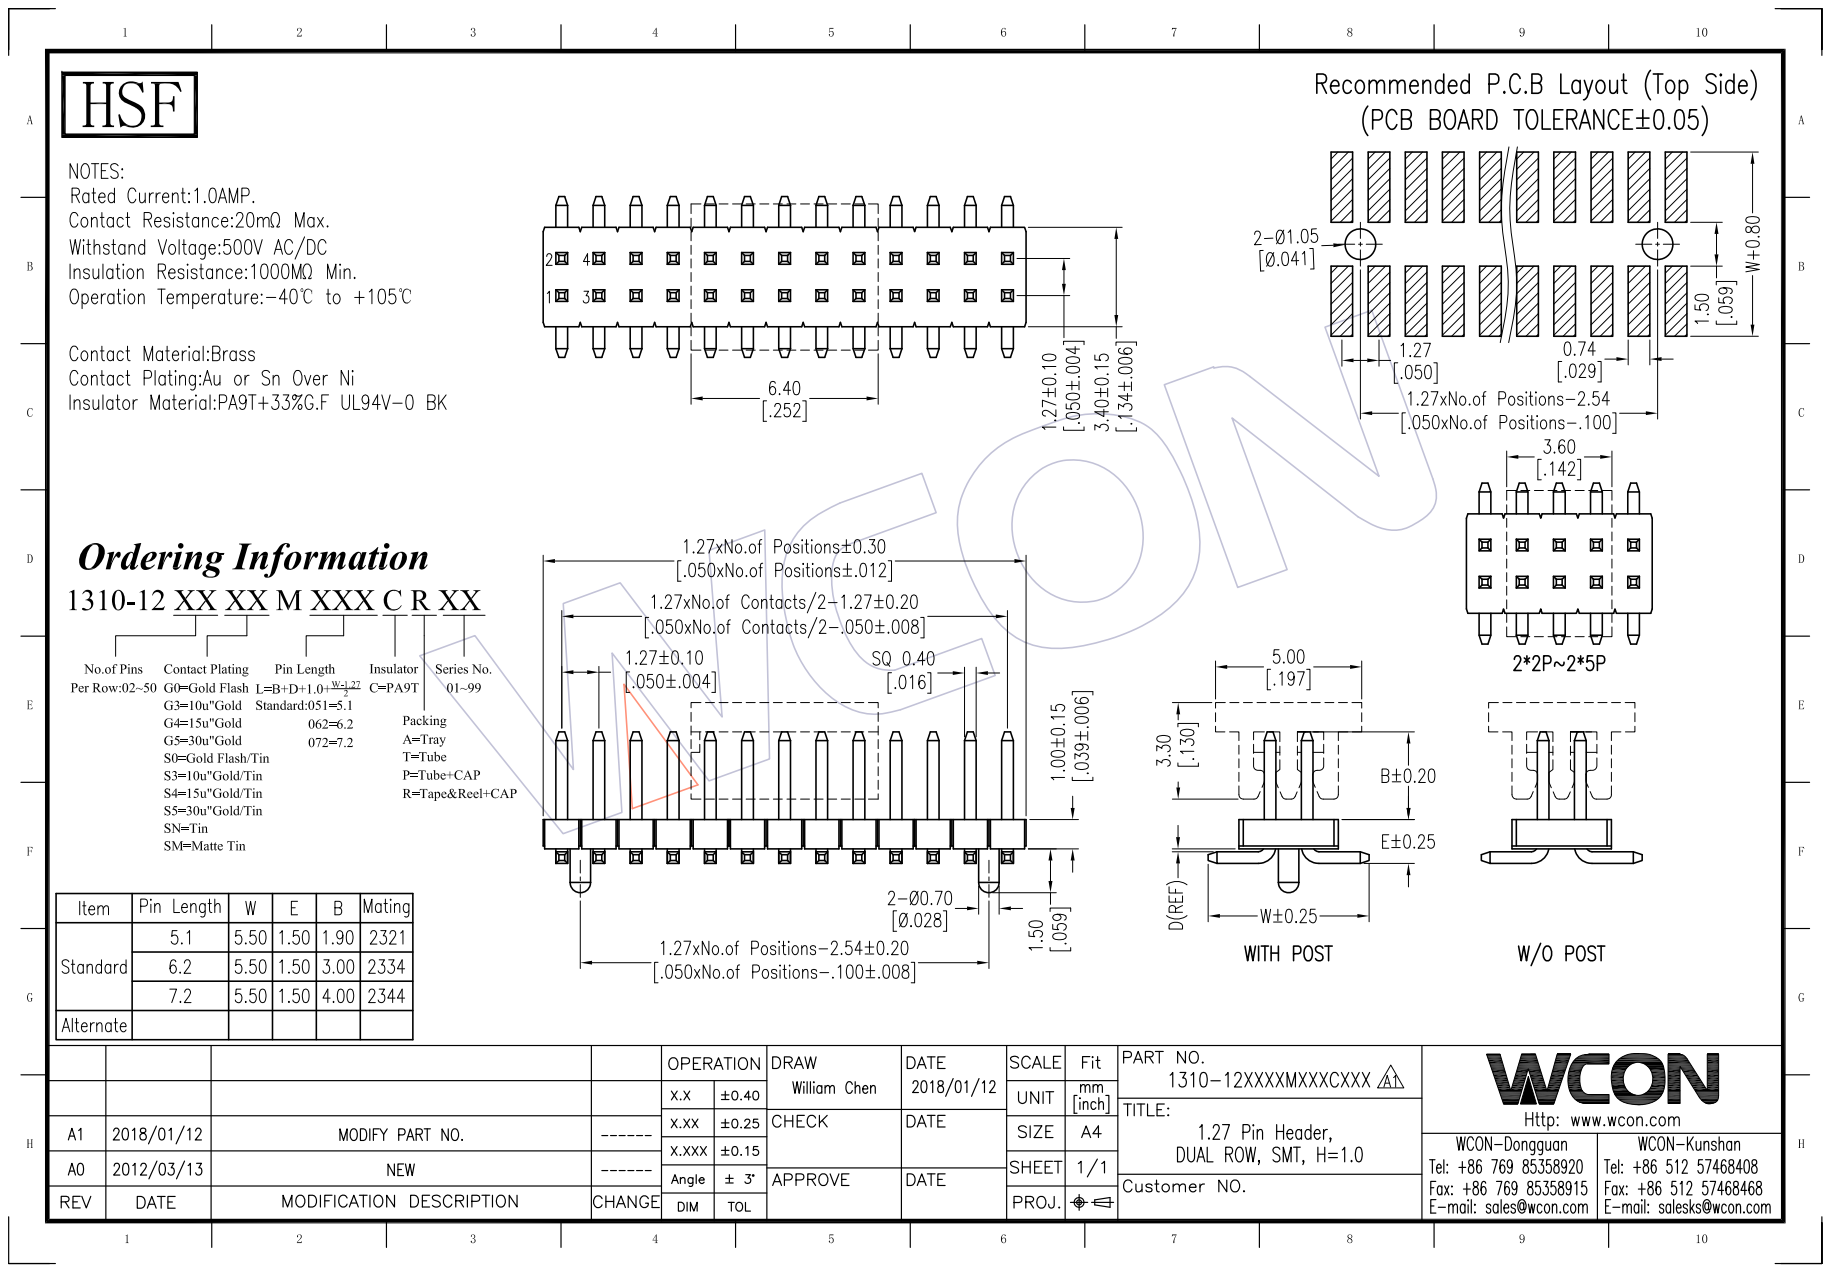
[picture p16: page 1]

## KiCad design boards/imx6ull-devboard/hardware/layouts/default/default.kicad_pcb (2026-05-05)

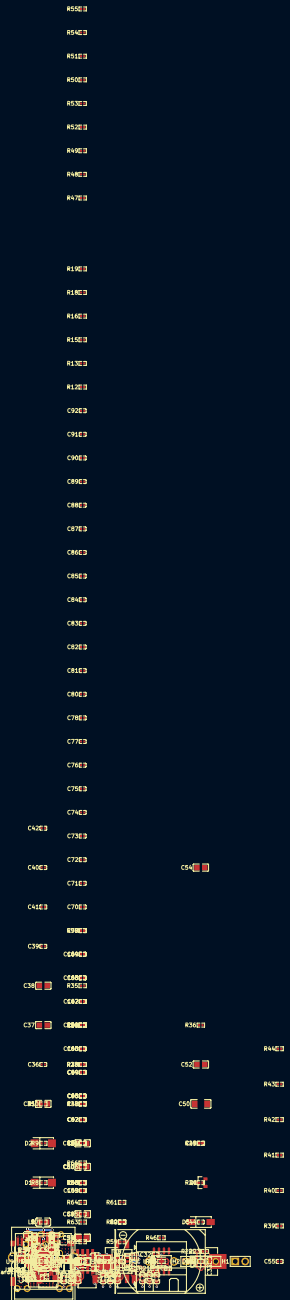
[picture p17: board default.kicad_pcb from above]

Board: 2 copper layers, 218 parts (0 on the bottom side), 172 nets.

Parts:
B1: BAT-TH_CR2032-BS-6-1
C1, C2, C3, C4, C10, C13, C17, C20, C24, C27, C36, C39, C43, C44, C45, C46, C49, C51, C53, C55, C65, C69, C70, C71, C72, C73, C74, C75, C76, C77, C78, C79, C80, C81, C82, C83, C84, C85, C86, C87, C88, C89, C90, C91, C92, C95, C96, C97, C98, C99, C100, C101, C102, C103, C104, C105, C106, C107, C108: 100nF ±10%; C0402
C5, C6, C31, C32, C33, C34, C48, C59, C61, C62, C63, C64: 1µF ±10%; C0402
C7: 470pF ±10%; C0402
C8, C9: 18pF ±5%; C0402
C11, C12, C18, C19, C25, C26, C37, C38, C47, C52, C56, C57, C60, C93, C94: 10µF ±10%; C0805
C14, C15, C16, C21, C22, C23, C28, C29, C30: 100nF ±10%; C0603
C35, C54, C58: 22µF ±20%; C0805
C40, C41, C42: 470nF ±10%; C0402
C50: 100µF ±20%; C1206
C66: 10nF ±10%; C0402
C67, C68: 22pF ±5%; C0402
C109: 1nF ±10%; C0805
CN1: CONN-TH_2P-P6.35_DB910-6.35-2P
CN2: CONN-SMD_1310-1205G0M061CR02
Card1: TF-SMD_TF-015
D1, D2: Vf {ℝ+}V; SMA_L4.3-W2.6-LS5.2-RD
D3, D6, D9: SOT-23-6_L2.9-W1.6-P0.95-LS2.8-BL
D4, D5: Vf {ℝ+}V; SMA_L4.4-W2.8-LS5.4-R-RD
F1, F2, F3: F0805
H1: HDR-TH_2P-P2.54-V-M
H2: HDR-TH_4P-P2.54-V-M
J1: RJ45-TH_HR911105A
L1, L2, L3: L 2.2µH ±20%; IND-SMD_L4.4-W4.2
L4, L5: L {ℝ+}H; L0805
Q1: Vgs ℝ+V; SOT-23_L2.9-W1.3-P1.90-LS2.4-BR
R1: 4.75kΩ ±1%; R0402
R2: 1.5kΩ ±1%; R0402
R3, R5, R28, R30, R45: 100kΩ ±1%; R0402
R4: 12.1kΩ ±1%; R0402
R6, R11, R13, R14, R15, R16, R17, R19, R31, R36, R39, R40, R44, R50, R52, R54, R59: 10kΩ ±1%; R0402
R7, R8, R9, R10: 49.9Ω ±1%; R0402
R12, R60, R61: 4.7kΩ ±1%; R0402
R18, R41, R47, R48: 1kΩ ±1%; R0402
R20: 6.34kΩ ±0.1%; R0402
R21: 2.8kΩ ±1%; R0402
R22: 13.7kΩ ±1%; R0402
R23: 16.9kΩ ±1%; R0402
R24, R25: 33Ω ±1%; R0402
R26, R27, R37, R38, R57, R58: 10kΩ ±1%; R0603
R29, R62: 1MΩ ±1%; R0402
R32, R33, R34, R35: 47kΩ ±1%; R0402
R42, R43: 680Ω ±1%; R0402
R46: 100Ω ±1%; R0402
R49, R56: 240Ω ±1%; R0402
R51: 8.2kΩ ±1%; R0402
R53: 7.5kΩ ±1%; R0402
R55: 33kΩ ±1%; R0402
R63, R64: 330Ω ±1%; R0402
R65, R66: 75Ω ±1%; R0402
SW1: SW-SMD_DSIC02LSGET
SW2: SW-SMD_4P-L5.1-W5.1-P3.70-LS6.5-TL_H1.5
U1: QFN-24_L4.0-W4.0-P0.50-TL-EP2.5
U2, U3, U4: SOT-23-6_L2.9-W1.6-P0.95-LS2.8-BR
U5: WSON-6_L2.0-W2.0-P0.65-TL-EP
U6: SOT-23-5_L3.0-W1.7-P0.95-LS2.8-BL
U7: SOP-8_L4.9-W3.9-P1.27-LS6.0-BL
U8: TQFN-16_L3.0-W3.0-P0.50-BL-EP1.5
U9: BGA-289_L14.0-W14.0-R17-C17-P0.80-BL
U10: TFBGA-96_L13.0-W7.5-R16-C6-P0.80-TL
U11: SOIC-8_L5.0-W4.0-P1.27-LS6.0-BL
USB1, USB2, USB3: USB-C-SMD_TYPE-C-6PIN-2MD-073
X1: OSC-SMD_4P-L3.2-W2.5-BL_SIT8008BI
X2: CRYSTAL-SMD_4P-L3.2-W2.5-BL
X3, X4: FC-135R_L3.2-W1.5

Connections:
1: U11.1, X4.1
2: U11.2, X4.2
4: R26.1, USB1.4
10: R27.1, USB1.10
A2: U9.P3, U10.A2
A3: U9.R1, U10.A3
A7: U9.P5, U10.A7
B8: U9.R2, U10.B8
BA0: U9.M1, U10.M2
BA1: U9.H1, U10.N8
BA2: U9.K2, U10.M3
BOB_SMITH: C109.1, R65.2, R66.2
C2: U9.R4, U10.C2
C3: U9.U3, U10.C3
C8: U9.U5, U10.C8
CD: Card1.9, R30.1, U9.M15
CDDAT3CS: Card1.2, R35.1, U9.A2
CHASSIS_GND: C109.2, J1.SH1, J1.SH2, R62.1
CK: U9.P1, U10.J7
CKE: U9.M3, U10.K9
CLKSCLK: Card1.5, U9.C1
CMDDI: Card1.3, R31.1, U9.C2
D7: U9.U2, U10.D7
DAT1RSV: Card1.8, R33.1, U9.B2
DAT2RSV: Card1.1, R34.1, U9.B1
DATA_N: D3.1, D3.6, U7.2, USB1.5, USB1.7
DATA_P: D3.3, D3.4, U7.1, USB1.6, USB1.8
DDR_A0: U9.L5, U10.N3
DDR_A4: U9.K4, U10.P8
DDR_A5: U9.L1, U10.P2
DDR_A6: U9.G2, U10.R8
DDR_A10_AP: U9.M4, U10.L7
DDR_A11: U9.K3, U10.R7
DDR_A12_nBC: U9.L4, U10.N7
DDR_A13: U9.H3, U10.T3
DML: U9.T7, U10.E7
DMU: U9.T3, U10.D3
DQL0: U9.T4, U10.E3
DQL1: U9.U6, U10.F7
DQL2: U9.T6, U10.F2
DQL3: U9.U7, U10.F8
DQL4: U9.U8, U10.H3
DQL5: U9.T8, U10.H8
DQL6: U9.T5, U10.G2
DQL7: U9.U4, U10.H7
DQSL: U9.P6, U10.G3
DQSU: U9.T1, U10.C7
DRAM_ADDR01: U9.H2, U10.P7
DRAM_ADDR02: U9.K1, U10.P3
DRAM_ADDR03: U9.M2, U10.N2
DRAM_ADDR07: U9.H4, U10.R2
DRAM_ADDR08: U9.J4, U10.T8
DRAM_ADDR09: U9.L2, U10.R3
DRAM_CAS_B: U9.J2, U10.K3
DRAM_CS0_B: U9.N2, U10.L2
DRAM_RAS_B: U9.M5, U10.J3
DRAM_RESET: U9.G4, U10.T2
DRAM_SDCLK0_N: U9.P2, U10.K7
DRAM_SDQS0_N: U9.P7, U10.F3
DRAM_SDQS1_N: U9.T2, U10.B7
DRAM_SDWE_B: U9.J1, U10.L3
DRAM_ZQPAD: R49.1, U9.N4
ENET1_RX_EN: U1.11, U9.E16
ENET1_RX_ER: R3.1, U1.10, U9.D15
ENET1_TX_CLK: U1.14, U9.F14
ENET1_TX_EN: U1.16, U9.F15
ETH_LED_LINK: J1.10, R5.1, U1.3
ETH_LED_SPEED: J1.12, R1.1, U1.2
ETH_N0_N: J1.8, R7.1, U1.22
ETH_N1_N: J1.3, R9.1, U1.20
ETH_P0_P: J1.4, R8.1, U1.23
ETH_P1_P: J1.1, R10.1, U1.21
GAIN_SLOT: R28.1, U8.2
GPIO1_IO00: R45.1, U9.K13
JTAG_MOD: R12.1, U9.P15
LED1_A: J1.9, R63.2
LED2_A: J1.11, R64.2
N_C_: U8.5, U8.6, U8.12, U8.13
N_TRST: R19.1, U9.N14
ODT: U9.N1, U10.K1
ONOFF: R13.1, U9.R8
POS: B1.1, R41.1
RBIAS: R4.1, U1.24
RTC_XTALI: U9.T11, X3.1
RTC_XTALO: U9.U11, X3.2
RX: H2.4, R25.2, U9.J16
RXD: R24.1, U7.7
RX_CT: J1.7, R65.1
SCK: U8.16, U9.D9
SCL: R60.1, U9.G17, U11.6
SD: U8.1, U9.E9
SDA: R61.1, U9.G16, U11.5
SW1A: R40.1, SW1.1, U9.U10
SW2A: R39.1, SW1.2, U9.T10
TCK: CN2.4, U9.M14
TDI: CN2.8, U9.N16
TDO: CN2.6, U9.N15
TEST_MODE: R18.1, U9.N7
TMS: CN2.2, U9.P14
TX: H2.3, R24.2, U9.J17
TXD: R25.1, U7.6
TX_CT: J1.2, R66.1
UART1_CTS_B: U1.13, U9.K15
UART1_RTS_B: R2.1, U1.12, U9.J14
USB_OTG1_VBUS: R46.2, U9.T12
VDD_SOC_IN: U9.H9, U9.H10, U9.J9, U9.J10, U9.K9, U9.K10
VFB: R52.1, R53.2, U3.4
WS: U8.14, U9.B8
ZQ: R56.1, U10.L8
_buck_1v35_out-hv: L2.2, L4.1, R53.1
_ldo_snvs_out-anode: C34.1, D2.2, R22.1, U6.5
_reset-line: R6.1, R15.1, U1.15, U9.L14
bootstrap_cap-power-hv: C17.1, U3.6
bootstrap_cap-power-hv-1: C10.1, U2.6
bootstrap_cap-power-hv-2: C24.1, U4.6
bootstrap_cap-power-lv: C17.2, L2.1, U3.2
bootstrap_cap-power-lv-1: C10.2, L1.1, U2.2
bootstrap_cap-power-lv-2: C24.2, L3.1, U4.2
c_rst_db-power-hv: C55.1, CN2.10, R16.1, R44.1, SW2.1, U9.P8
cap_ud_dram-power-hv: C61.1, U9.N6
cap_ud_high-power-hv: C62.1, U9.R14, U9.R15
cap_ud_snvs-power-hv: C63.1, U9.N12
cap_ud_usb-power-hv: C64.1, U9.R12
cap_vref_lf-power-hv: C65.1, C66.1, R47.1, R48.2, U9.P4, U10.H1, U10.M8
cap_xtal_a-power-hv: C67.1, U9.T16, X2.1
cap_xtal_b-power-hv: C68.1, U9.T17, X2.3
cathode: B1.2, C1.2, C2.2, C3.2, C4.2, C5.2, C6.2, C7.2, C8.2, C9.2, C31.2, C33.2, C34.2, C35.2, C36.2, C37.2, C38.2, C39.2, C40.2, C41.2, C42.2, C43.2, C44.2, C45.2, C46.2, C47.2, C48.2, C49.2, C50.2, C51.2, C52.2, C53.2, C54.2, C55.2, C56.2, C57.2, C58.2, C59.2, C60.2, C61.2, C62.2, C63.2, C64.2, C65.2, C66.2, C67.2, C68.2, C69.2, C70.2, C71.2, C72.2, C73.2, C74.2, C75.2, C76.2, C77.2, C78.2, C79.2, C80.2, C81.2, C82.2, C83.2, C84.2, C85.2, C86.2, C87.2, C88.2, C89.2, C90.2, C91.2, C92.2, C93.2, C94.2, C95.2, C96.2, C97.2, C98.2, C99.2, C100.2, C101.2, C102.2, C103.2, C104.2, C105.2, C106.2, C107.2, C108.2, CN1.2, CN2.3, CN2.5, CN2.9, Card1.6, Card1.10, Card1.11, Card1.12, Card1.13, D3.2, D6.2, D9.2, H2.1, R1.2, R3.2, R4.2, R5.2, R12.2, R15.2, R18.2, R23.2, R26.2, R27.2, R28.2, R36.2, R37.2, R38.2, R47.2, R49.2, R50.2, R52.2, R54.2, R56.2, R57.2, R58.2, R62.2, SW1.3, SW1.4, SW2.3, U1.25, U2.1, U3.1, U4.1, U5.3, U6.2, U7.3, U8.3, U8.11, U8.15, U8.17, U9.A1, U9.A17, U9.C3, U9.C7, U9.C11, U9.C15, U9.E8, U9.E11, U9.F6, U9.F7, U9.F8, U9.F9, U9.F10, U9.F11, U9.F12, U9.G3, U9.G5, U9.G7, U9.G12, U9.G15, U9.H7, U9.H12, U9.J5, U9.J7, U9.J12, U9.K7, U9.K12, U9.L3, U9.L7, U9.L12, U9.M7, U9.M8, U9.M9, U9.M10, U9.M11, U9.N3, U9.N5, U9.R3, U9.R5, U9.R7, U9.R11, U9.R16, U9.R17, U9.T14, U9.U1, U9.U14, U9.U17, U10.A9, U10.B1, U10.B3, U10.B9, U10.D1, U10.D8, U10.E1, U10.E2, U10.E8, U10.F9, U10.G1, U10.G8, U10.G9, U10.J2, U10.J8, U10.M1, U10.M9, U10.P1, U10.P9, U10.T1, U10.T9, U11.4, USB1.1, USB1.12, USB1.13, USB1.14, USB1.15, USB1.16, USB2.1, USB2.12, USB2.13, USB2.14, USB2.15, USB2.16, USB3.1, USB3.12, USB3.13, USB3.14, USB3.15, USB3.16, X1.2, X1.4, X2.2, X2.4
connector-cc[0]-4: R57.1, USB3.4
connector-cc[0]-4-1: R37.1, USB2.4
connector-cc[1]-10: R58.1, USB3.10
connector-cc[1]-10-1: R38.1, USB2.10
connector-power_vbus-hv: F1.1, USB1.2, USB1.11
connector-power_vbus-hv-1: F3.1, USB3.2, USB3.11
connector-power_vbus-hv-2: F2.1, USB2.2, USB2.11
dat[0]-line: Card1.7, R32.1, U9.B3
decoupling_capacitor-power-hv: C45.1, D3.5, F1.2
en_delay_1v4-power-hv: C40.1, R11.1, U2.5
en_delay_1v35-power-hv: C41.1, R14.1, U3.5
en_delay_3v3-power-hv: C42.1, R17.1, U4.5
feedback_divider-ref_out-hv: R20.2, R21.1, U5.2
feedback_divider-ref_out-hv-1: R22.2, R23.1, U6.4
gate: Q1.1, R36.1
hv: C43.1, U7.8
line: R42.1, U9.L17
lv: C32.2, R21.2, U5.7
nINT: R59.1, U9.M16, U11.3
nSD_MODE: R29.1, U8.4
or_bench-anode: D4.1, Q1.2
phy-rmii-line: U1.18, U9.E14
phy-rmii-line-1: U1.17, U9.E15
phy-rmii-line-2: U1.7, U9.E17
phy-rmii-line-3: U1.8, U9.F16
pin_in-POS: CN1.1, Q1.3
power-anode: C53.1, D5.1, D6.5, F2.2
power_1v4_arm-hv: C57.1, C80.1, C81.1, C82.1, C83.1, L1.2, L5.1, R51.1, U9.G9, U9.G10, U9.G11, U9.H11
power_1v4_soc-hv: C38.1, C39.1, C60.1, C91.1, C92.1, L5.2, U9.G8, U9.H8, U9.J8, U9.J11, U9.K8, U9.K11, U9.L8, U9.L9, U9.L10, U9.L11
power_1v8-hv: C32.1, R20.1, U5.1
power_1v35-hv: C35.1, C36.1, C58.1, C84.1, C85.1, C86.1, C87.1, C88.1, C89.1, C93.1, C94.1, C95.1, C96.1, C97.1, C98.1, C99.1, C100.1, C101.1, C102.1, C103.1, C104.1, C105.1, C106.1, L4.2, R48.1, U9.G6, U9.H6, U9.J6, U9.K6, U9.L6, U9.M6, U10.A1, U10.A8, U10.B2, U10.C1, U10.C9, U10.D2, U10.D9, U10.E9, U10.F1, U10.G7, U10.H2, U10.H9, U10.K2, U10.K8, U10.N1, U10.N9, U10.R1, U10.R9
power_3v3-cathode: C1.1, C2.1, C3.1, C4.1, C5.1, C31.1, C37.1, C46.1, C47.1, C48.1, C51.1, C54.1, C56.1, C59.1, C69.1, C70.1, C71.1, C72.1, C73.1, C74.1, C75.1, C76.1, C77.1, C78.1, C79.1, C90.1, C107.1, C108.1, CN2.1, Card1.4, D1.1, D2.1, D9.5, F3.2, H2.2, L3.2, R2.2, R6.2, R7.2, R8.2, R9.2, R10.2, R13.2, R16.2, R19.2, R29.2, R30.2, R31.2, R32.2, R33.2, R34.2, R35.2, R39.2, R40.2, R43.1, R44.2, R45.2, R46.1, R55.1, R59.2, R60.2, R61.2, R63.1, R64.1, U1.1, U1.9, U1.19, U5.4, U5.6, U8.7, U8.8, U9.C4, U9.E7, U9.E13, U9.F4, U9.F13, U9.H13, U9.J13, U9.L13, U9.M13, U9.N13, U9.P12, U9.P13, U11.8
power_5v-cathode: C33.1, C44.1, C49.1, C50.1, C52.1, D4.2, D5.2, R11.2, R14.2, R17.2, U2.3, U3.3, U4.3, U6.1, U6.3, U7.5
psu.buck_1v4-VFB: R50.1, R51.2, U2.4
psu.buck_3v3-VFB: R54.1, R55.2, U4.4
speaker_n: H1.2, U8.10
speaker_p: H1.1, U8.9
usb_dp_dn-DATA_N: D9.1, D9.6, U9.T15, USB3.5, USB3.7
usb_dp_dn-DATA_P: D9.3, D9.4, U9.U15, USB3.6, USB3.8
usbc_pd-usb-DATA_N: D6.1, D6.6, USB2.5, USB2.7
usbc_pd-usb-DATA_P: D6.3, D6.4, USB2.6, USB2.8
vbat_in-anode: D1.2, R41.2
vddcr_caps[1]-power-hv: C6.1, C7.1, U1.6
xtal_caps[0]-power-hv: C8.1, U1.5, X1.1
xtal_caps[1]-power-hv: C9.1, U1.4, X1.3

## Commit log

2026-05-05 Initial scaffold: README, PLAN, license
    Project: full-stack open-source agent-driven i.MX 6ULL Linux dev board.
2026-05-05 atopile knowledge pack + working hello-world
    - Add CLAUDE.md (atopile knowledge pack, scoped to hardware dir, distilled from atopile's official Claude skill at .claude/skills/ato-language/SKILL.md plus i.MX 6ULL project-specific context, missing-package list, and pitfalls).
    - Verified atopile 0.15.7 toolchain end-to-end: scratch/hello_resistor/ builds a single 10kΩ pull-down to KiCad PCB + BOM + datasheet (LCSC C25744 picked) in 5s.
    - Updated CLI section to match the actual installed binary surface.
    [R0402_L1.0-W0.5-H0.4.step, default.kicad_pcb]
2026-05-05 Acquire i.MX 6ULL datasheet + reference design + DDR3 candidates
    - Cloned yu-mingfu/IMX6ULL_Core_Board reference (gitignored), bundled the full MCIMX6Y2CVM08AB datasheet (138p, NXP rev 1.2), Nanya DDR3 candidate datasheets, eMMC, and the core-board schematic PDF.
    - Pulled NXP AN5121 hardware design checklist.
    - datasheets/README.md tracks acquired vs gated docs (full Reference Manual + HDG are behind NXP login — TODO).
2026-05-05 Install official atopile Claude skill via ai-builder
    - npx ai-builder add skill atopile/ato → .claude/skills/ato/SKILL.md (1505 lines, authoritative).
    - CLAUDE.md updated to note it's a project-specific layer on top of the official skill.
2026-05-05 Bootstrap real board project + Docling RAG venv
    - boards/imx6ull-devboard/hardware/: atopile project scaffolded with Board top-level module
    declaring 5V and 3V3 rails. Builds clean.
    - mcp/datasheet-server/: uv project with Docling 2.92.0 installed, smoke-tested on AN5121.
    Image-export config + LanceDB index + FastMCP server pending.
    - KiCad 10.0.1 installed locally (cask).
    [default.kicad_pcb]
2026-05-05 Acquire RM + HDG; lock USB-C PD power input + discrete buck/LDO tree
    - IMX6ULLRM Rev 0 (3899p) and IMX6ULLHDG Rev 0 (53p) downloaded from public mirrors
    (whqee.cn, zlgmcu.com) — bypasses NXP login wall. Both verified genuine via cover/metadata.
    - PLAN.md: power input topology (USB-C PD via HUSB238 + bench supply, two-source
    Schottky OR — safe because manual-select), reverse-polarity P-FET on bench, parts table
    (5/6 lines on JLC Basic).
    - PLAN.md: discrete buck/LDO power tree from 5V_BOARD with sequencing note.
2026-05-05 Block diagrams: top-level system + power tree (mermaid)
    - diagrams/system.mmd: full block view — MPU center, DDR3, Ethernet, two USB-Cs (power
    + data), audio amp, JTAG, microSD, console paths.
    - diagrams/power_tree.mmd: focused buck/LDO chain with current budgets and sequencing
    callout (VDD_SNVS → VDD_HIGH → VDD_SOC → NVCC_DRAM).
    - Two separate USB-C connectors (decided): one power-only via HUSB238, one OTG-only.
2026-05-05 Verified BoM via live JLC sweep + flagged corrections
    - boards/imx6ull-devboard/hardware/BOM.md: 20-line BoM with verified LCSC/JLC status,
    stock counts, qty-10 prices.
    - Corrections from sweep: HUSB238 C2829277 was wrong (terminal block) → C7471904.
    Terminal block C8270 is 3-pin not 2-pin → need WJ128V-5.0-02P C-number.
    - Low-stock flags: Nanya DDR3 (79 units), TPS51200 (881 units) — backup parts listed.
    - Reality: 3/20 lines Basic, ~17 Extended → ~$51 in PCBA setup fees. Unavoidable for
    Linux-class board.
2026-05-05 Ethernet subsystem v0 — wired + reviewed
    - src/network.ato: LAN8742A wrapper consuming the atopile package, plus wrapper-level
    fixes for two CRITICAL bugs the reviewer agent caught in atopile/microchip-lan8742a@0.3.0:
    * nINTSEL strap pulldown (4.75kΩ) so PHY drives 50MHz REF_CLK to MAC at boot
    * MDI termination (4× 49.9Ω 1% on TXP/TXN/RXP/RXN to VDDA) per Microchip Checklist
    Plus: 1.5kΩ MDIO pullup (IEEE 802.3 open-drain), MDC pullup removed (push-pull).
    - src/main.ato: Network module wired in; restructured paths.src to ./src.
    - docs/subsystems/{README,ethernet}.md: design doc with reviewer findings table,
    open TODOs for HR911105A magjack + Bob Smith + ESD + crystal cap u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
    [C0402_L1.0-W0.5-H0.5.step, R0402_L1.0-W0.5-H0.4.step, default.kicad_pcb]
2026-05-05 Power Tree subsystem v0 — wired + reviewed (6 fixes applied)
    Subsystems: 3x TPS563201 buck (3V3, 1V4, 1V35) + TLV75901 LDO (1V8) + LDK220 LDO
    (SNVS) with reviewer-driven fixes:
    * EN-pin RC delay caps (470nF) so SNVS LDO comes up before any buck soft-start
    * Coin-cell OR'd into power_snvs via 2x SS34 Schottkys with vbat_in interface
    * Ferrite bead split between VDDARM and VDDSOC (NXP HDG §4.2)
    * Ferrite bead + 22µF bulk on NVCC_DRAM output (DDR3L ripple budget)
    * Inductor saturation requirement bumped to ≥4.5A (above OCL peak)
    * 1V35 setpoint tightened to ±4% (DDR3L Vddq abs-max headroom)
    Deferred reviewer items:
    - 5V inrush control → Power Input subsystem
    - Multi-r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
    [C0402_L1.0-W0.5-H0.5.step, C0805_L2.0-W1.3-H1.3.step, IND-SMD_L5.0-W5.0-H1.2_SMNR5030.step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]
2026-05-05 USB-UART subsystem v0 — CH340N → USB-C #3
    CH340N (SOP-8, $0.48) USB-to-UART bridge for board console. Powered from 5V_BOARD
    (simpler than VBUS, avoids backfeed). USB-C #3 (TYPE-C-31-M-17, commonized with
    PD #1 and OTG #2). 33Ω series on TX/RX for edge-rate slowing + accidental-short
    current limit.
    Generated WCH_CH340N atomic part via `ato create part --search C2977777` —
    first use of that flow in the project. Flow worked cleanly.
    TODO (deferred to Debug subsystem): 4-pin TTL header tapped to same UART1 lines
    for users with their own USB-TTL dongle.
    [R0402_L1.0-W0.5-H0.4.step, R0603.STEP, SOP-8_L4.9-W3.9-P1.27-LS6.0-BL-1.STEP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]
2026-05-05 Audio + microSD subsystems v0
    Audio: MAX98357A I²S Class-D 3W mono. nSD_MODE=VDD (stereo sum), GAIN=GND (+9dB),
    ferrite + 1nF snubber on each output (commonized ferrite C1017). 3V3 VDD.
    microSD: SOFNG TF-015 push-push slot, 4-bit SD mode, 3V3 signaling (no UHS-I),
    direct 3V3 VDD (no power-cycle FET in v0). CMD 10kΩ + DAT[3:0] 47kΩ + CD 100kΩ
    pull-ups per SD spec §3.2.
    Both built clean. Atomic parts created via `ato create part`:
    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
    [C0402_L1.0-W0.5-H0.5.step, R0402_L1.0-W0.5-H0.4.step, TQFN-16_L3.0-W3.0-P0.50-BL-EP1.5.STEP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]
2026-05-05 Power Input + reviewer fixes for USB-UART/Audio/microSD
    Power Input subsystem v0:
    - USB-C #1 (built-in 5.1kΩ Rd + fuse + ESD) → SS54 ── 5V_BOARD
    - Bench DIBO terminal block → AO3401A rev-pol P-FET → SS54 ── 5V_BOARD
    - 100µF + 10µF + 100nF bulk on 5V_BOARD
    - Dropped HUSB238 for v0: connector's integrated Rd is sufficient for
    Vsafe5V from any USB-C source (sources advertise 1.5A/3A via Rp).
    Atomic part kept under src/parts/ for v2 swap-in if needed.
    Batch reviewer fixes (USB-UART + Audio + microSD):
    - CRITICAL Audio nSD_MODE: was 100kΩ→VDD (= "Left only" with internal
    100kΩ pulldown forming a divider at 1.65V). Fixed to 1MΩ for SD≈0.30V
    in the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
    [C1206_L3.2-W1.6-H1.3.step, CONN-TH_2P-P6.35_DB910-6.35-2P.step, DFN-10_L3.0-W3.0-P0.50-BL-EP2.5.STEP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]
2026-05-05 Debug subsystem v0 — JTAG, reset, boot DIP, LEDs, coin cell, headers
    Components:
    - 10-pin Cortex JTAG/SWD SMD header (Wcon, 1.27mm) with named pins
    per ARM debug spec (VTREF/SWDIO_TMS/SWCLK_TCK/SWO_TDO/TDI/NSRST/GNDs)
    - SMD tactile reset button (XKB, JLC Basic) + 10kΩ pullup + 100nF debounce
    - 2-position SMD DIP for BOOT_MODE[1:0] selection (kangshen DSIC02LSGET)
    with truth table documented; default position = SD boot
    - 2x status LEDs (3V3 power-good always-on, MPU-driven heartbeat) via
    bridge pattern: power_3v3.hv ~> R ~> LED ~> power_3v3.lv
    - CR2032 coin cell holder (Q&J) + 1kΩ charge limit → PowerTree.vbat_in
    - 4-pin TTL UART header (atopile/pin-headers Male_2_54mm_1x4P_TH) fo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
    [BAT-SMD_L28.5-W16.0-H5.5-LS31.3_CR2032-BS-6-1.STEP, CONN-SMD_1310-1205G0M061CR02.step, R0402_L1.0-W0.5-H0.4.step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]
2026-05-05 WIP: i.MX 6ULL MPU module — pinmux verified + Board wired, build blocked on picker
    MPU module written with research-verified pinmux assignments (NOT guesses):
    - SAI3 on LCD_HSYNC/ENABLE/RESET (NOT SAI2 — SAI2 only muxes to JTAG or SD1
    pads on i.MX 6ULL, would kill JTAG or USDHC1)
    - MDIO/MDC on UART1_CTS_B/RTS_B (K15/J14) per imx6ul-pinfunc.h
    - SD_CD on GPIO1_IO09 (M15)
    - ETH_PHY_RESET on GPIO1_IO02 with 10kΩ pulldown (PHY held in reset until firmware)
    - JTAG_MOD via 4.7kΩ to GND (RM §59 Secure JTAG normal mode)
    - TEST_MODE via 1kΩ to GND (mandatory)
    - ONOFF + POR_B pull-ups to VDD_SNVS_IN (NOT 3V3 — SNVS-domain inputs)
    - USB_OTG1_VBUS divider (20k/30k → ~3V) p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
    [BGA-289_L14.0-W14.0-H1.4-P0.8.step, default.kicad_pcb]
2026-05-05 PLAN.md: document picker contradiction investigation
    Verified root constraint chain by reading faebryk's AdjustableRegulator.py and
    ResistorVoltageDivider.py source: feedback_divider.v_in is bound to
    power_out.voltage, ratio = R[1]/(R[0]+R[1]) = v_out/v_in, so pinning R values
    fully determines the output rail voltage to within Vref tolerance.
    Six attempts tried (tolerance loosening ±5/±7/±10%, R-value pinning, current
    pinning, total_resistance pinning, single-buck diagnostic, lcsc_id pinning) —
    all hit the same Contradiction. lcsc_id "C25817" not in atopile's part DB.
    Next concrete steps documented: read DiscreteSystem solver source, find
    working 33kΩ LCSC C-number, fork ti-tps563201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
2026-05-05 Local fork of ti-tps563201 — picker contradiction RESOLVED
    Forked atopile/ti-tps563201@0.2.0 into src/parts/local_buck/local_buck.ato:
    - Dropped `from AdjustableRegulator` inheritance (which dragged in
    ResistorVoltageDivider's ratio/v_in/v_out coupling that was unsatisfiable
    with our project's many power_3v3 consumers)
    - Hand-wired two Resistor instances per buck with explicit resistance
    values (33k/10k for 3V3, 8.2k/10k for 1V4, 7.5k/10k for 1V35) wired
    directly from VOUT → VFB → GND, no ResistorVoltageDivider
    - Three concrete modules: LocalBuck_3V3, LocalBuck_1V4, LocalBuck_1V35
    - Imports the upstream chip atomic part via package path (no duplication)
    - Keep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
    [C0402_L1.0-W0.5-H0.5.step, C0603_L1.6-W0.8-H0.8.step, IND-SMD_L4.2-W4.4-H2.0.step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]
2026-05-05 🚀 BUILD SUCCESSFUL — 58-part Linux dev board in KiCad
    All 14 build stages green. 1.26 MB default.kicad_pcb generated.
    Two fixes that closed the build:
    1. Net name collisions (segfault → crash):
    Set explicit override_net_name on top-level rails (VCC_5V, VCC_3V3,
    VCC_1V4_ARM, VCC_1V4_SOC, VCC_NVCC_DRAM, VCC_1V8, VCC_SNVS, VBAT, GND)
    in main.ato:Board. atopile's PCB writer was crashing when auto-derived
    net names like "hv"/"lv"/"cathode" collided across modules. Explicit
    names give the writer deterministic output and the segfault disappeared.
    2. Broken MPU pin numbers (29 lines):
    The auto-generated NXP_Semicon_MCIMX6Y2CVM08AB part from `ato create part`
    had 29 pin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
    [default.kicad_pcb]
2026-05-05 DDR3 module written + datasheet-verified, build blocker documented
    DDR3 subsystem (Nanya NT5CC128M16JR-EK, 96-ball TFBGA, 256 MB):
    - src/ddr3.ato: 89-line wrapper, full pin mapping verified against datasheet
    pages 4-7. DQSL pair fix (was swapped in auto-gen). 12× 100nF decoupling +
    2× 10µF bulk + 240Ω ZQ resistor. VREFCA + VREFDQ both via bus.vref.
    - src/parts/Nanya_Tech_NT5CC128M16JR_EK/: atomic part with fixes:
    * 6 NC pads added (J1, J9, L1, L9, M7, T7)
    * Address signals prefixed (DDR_A0, DDR_A4, etc.) to avoid collision
    with i.MX 6ULL BGA pad coordinates
    - mpu.ato: added vref field to DDR3Bus interface, wired DRAM_VREF to it
    - docs/subsystems/ddr3.md: full design doc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
    [TFBGA-96_L13.0-W7.5-H1.1-R16-C6-P0.80-TL.step, default.kicad_pcb]
2026-05-05 Wire crystals, USB-C OTG, RJ45 magjack, and I²C RTC — 4 schematic-side blockers fixed
    - Crystals (#1): real 24 MHz YXC X322524MOB4SI (C70590) + 2× Epson FC-135
    (C32346, one for SoC RTC and one for the new external RTC). Kills the prior
    "no footprint for xtal_main / xtal_rtc" warnings — board now has a clock.
    - USB-C OTG #2 (#2): new src/usb_otg.ato wrapping atopile/usb-connectors
    (5.1k CC pulldowns → UFP/device, 1A fuse, USBLC6 ESD). Fixed the broken
    20k/30k VBUS divider in mpu.ato that pulled VBUS to 3V at the chip pin —
    i.MX VBUS_VALID threshold is ~4.4V, so OTG would never have enabled.
    Replaced with a 100Ω series resistor per NXP AN12028. ID pin pulled HIGH
    insi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
    [C0805_L2.0-W1.3-H1.3.step, FC-135R_L3.2-W1.5.STEP, OSC-SMD_L3.2-W1.5-H0.8.STEP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]
